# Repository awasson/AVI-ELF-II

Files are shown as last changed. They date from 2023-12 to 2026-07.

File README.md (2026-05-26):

# AVI ELF II Rev D Variant

**The AVI ELF II Rev D Variant is a reproduction of the RCA  CDP1802-based computer kit by Netronics Research and Development Limited.**

ELF II Rev D Variant

The AVI ELF II Rev D Variant single board microcomputer is a replica of the Netronics ELF II microcomputer that was reimagined by the late Ed Keefe (1964-2022) to maintain the aesthetic of the original ELF II, with additional onboard RAM and daughter cards for flexibility of keypad encoders and display drivers.

This project is ongoing with the support of [Josh Bensadon](https://github.com/JoshBensadon), [Andrew Wasson](https://github.com/awasson), Walter Miraglia, [Costas Skordis](https://github.com/cskordis) and Rizal Acob. Below you will find a stable version of the PCB gerber files, bill of materials. 

[The Assembly Manual](https://github.com/awasson/AVI-ELF-II/wiki/AVI-ELF-II-Detailed-Assembly-Notes) is in the Wiki and this covers building the mainboard and the expansion boards. 

**There are a number of differences between the AVI ELF II and the original:**

* Power on/off toggle switch with power status LED.
* Power is from a single 6 to 9 volt DC supply that supplies the board and expansion cards. Suitable for use with typical 9 volt adapter with barrel connector (center positive). If a V7805-2000R (DC DC CONVERTER 5V 10W) is used in place of the LM7805 voltage regulator, up to 2A of current is available for the board and expansion boards.
* Optional on-board DC-DC coverter for +8 volt / -8 volt supply for original Netronics Giant Board.
* 32KB on-board RAM with ability to adjust RAM size from 256 Bytes to 32KB.
* Optional onboard RAM battery backup.
* Keypad uses modern Cherry MX compatible keyswitches.
* The keypad input switch has improved debouncing over the original ELF II keypad.
* Optional raised Keypad to approximate height of keypad on the original Netronics ELF II.
* Onboard Data Display options for original HP 5082-7740 7-Segment Displays or HP 5082-7340 Dot Matrix LED Display.
* Optional raised display boards for TIL 311 or Dot Matrix Address and Data Displays. 

### What does it do?
Initially, we approached this project with the goal to faithfully reporduce the original Netronics ELF II with added flexibility to choose several LED display types, maximize user RAM for programs and use modern keyswitches. We also planned to add a modern equivalent of the Netronics Giant Board called the Hyperboard. As we workeed through development and testing, we realized that the ELF II provides the perfect springboard to support a variety of 1802 powered systems.

**A faithful reproduction of the original ELF II**\
If all you are looking for is a journey back to the late 70's, with a trusty ELF II and all of the RAM you could possibly use then, the AVI ELF II main board is all you need. It will respond and function as an exact replica of the original and if you squint at it from several feet away, it looks pretty close to the real McCoy. If you want to have the expansion possibilities that you would have enjoyed with the original system expanded with a Netronics Giant Board and the Giant Monitor, you can add a AVI Hyperboard to the mix.   

**A state of the art (circa 1979) ELF II workstation**\
The combination of an AVI ELF II main board, AVI Hyperboard (or Netronics Giant Board) and the AVI Reproduction Full BASIC Math/ROM Card, provides the top of the line Netronics ELF II microcomputer workstation of the time. It can be paired with the original ASCII keyboard/display or a serial terminal. Power on and it boots into the Giant Monitor where you can run, inspect or program in machine language or type in 00 (RUN) 0003 on the HEX keypad and it boots into Netronics Basic Level III (By Larry Sandlin) and you can use all of the built in RPN Math Co-processor features (bugs and all). Details to come in a new wiki page under development.    

**An ELF2K compatible ELF/OS machine with the Aesthetics and features of the ELF II platform**\
Uses the STG ELF2K to ELF II board and AVI ELF II TIL311 6-Digit Display Card described below.\
More details to come... 

**An RCA VIP Capable ELF II**\
Uses the ELF II SD Card and VIP Keyboard For ELF II described below. Optionally add Cassette Board for loading and saving to cassette tape.\
More details to come... 

**An RCA Studio II Capable ELF II**\
In development. Will require the VIP Keyboard for ELF II and secondary VIP Keyboard for ELF II + the Hyperboard or ELF II SD Card board.\
More details to come... 

### Build Notes & Assembly Manual
* [Detailed Assembly Notes](https://github.com/awasson/AVI-ELF-II/wiki/AVI-ELF-II-Detailed-Assembly-Notes)

### Design Files:
* [Schematic](notes/ELF-II/AVIELF2v1-Sch.pdf)
* [Bill of Materials](notes/ELF-II/AVI%20ELF%20II%20Final%20BOM.xlsx)
* [FAB Files](gerbers/ELF-II/AVIELF2v1-Gerbers.zip)

## Expansion Boards
Aside from the novelty of having a retro-replica of one of the most sought after Cosmac ELF variants, the fun begins when you add expansion boards to add features and extend the capabilities of the ELF II microcomputer. Several Expansion boards have been designed to enhance and extend the ELF II. These were designed primarily for use with the AVI ELF II but it is quite possible that many will work with an orginal Netronics ELF II. 

* **AVI Hyperboard 2.0 Expansion Card**\
The Hyperboard is a modern take on the Netronics ELF II Giant Board which includes additional RAM and EEPROM, input/output ports and serial connections with 32KB RAM / 32KB EPROM, CD1852 Byte-Wide Input/Output Ports, CD1854 UART, Cassette IN/OUT with proto area. The board was slightly revised in 2026 to add the ability to reserve/allocate address space on the address bus for use with add-on boards that have their own boot loading software on board, like the Netronics BASIC/MATH/ROM board.\
\
The original Hyperboard is documented for historical usage, in the [Hyperboard 1.0 Build Notes and Assembly Manual](https://github.com/awasson/AVI-ELF-II/wiki/AVI-Hyperboard-Expansion-Card-Assembly-Notes).\
\
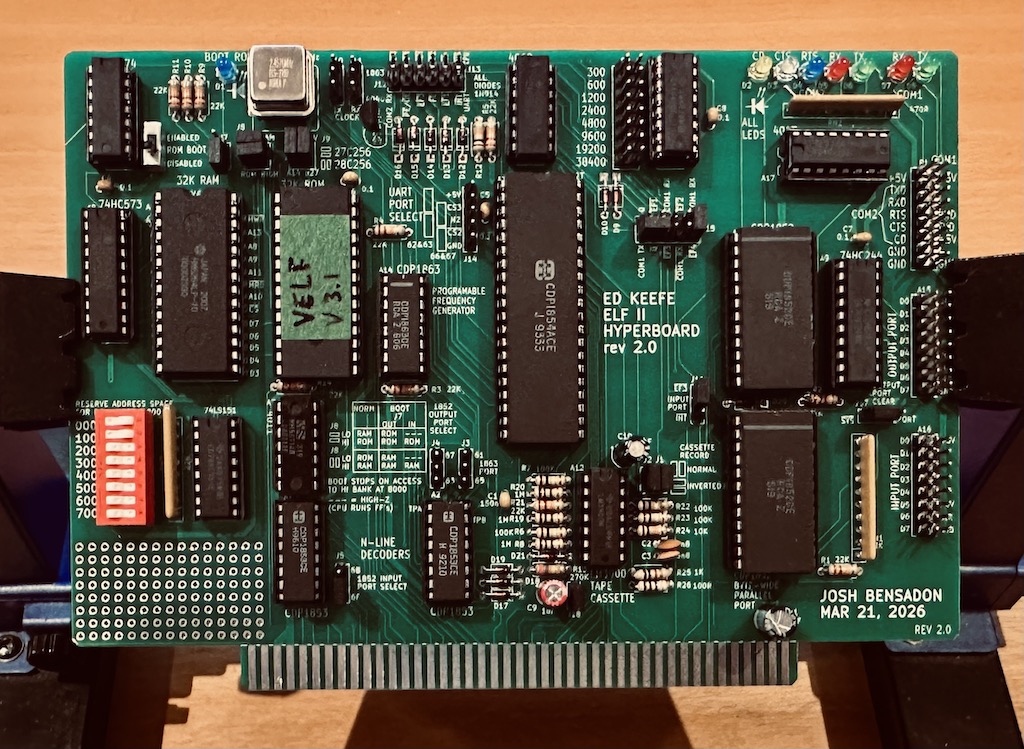
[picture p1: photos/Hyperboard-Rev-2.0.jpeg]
\
\
If the goal for your AVI ELF II is a fully expanded period computer from the late 1970's, the Hyperboard is a good addition to begin with. The Hyperboard will run new firmware readily and also runs period software including the Netronics Giant Monitor for automating entry, inspection and running programs. The Hyperboard also enables loading and saving programs from cassete tape.
   * [Get the schematics here](notes/Hyperboard-Rev-2/AVIELF2HYPERBOARD-KiCad-Rev2.pdf)
   * [Get the Gerber Files here](gerbers/Hyperboard-Rev-2/AVIELF2HYPERBOARD-Rev-2-gerbers.zip)
   * [Build Notes and Assembly Manual](https://github.com/awasson/AVI-ELF-II/wiki/AVI-Hyperboard-Rev-2.0-Expansion-Card-Assembly-Notes)<br/><br/>

* **STG ELF 2K Disk for ELF II Card**\
Uses Spare Time Gizmos ELF 2K Firmware to add a Compact Flash Card "Hard Disk" to use with the ELF/OS Disk Operating System. Provides 32KB RAM / 32KB EPROM, 16C450 UART, Serial Communications with FTDI connections, USB FT232RL device, IDE connection, CF Card socket and Real Time Clock chip.\
\
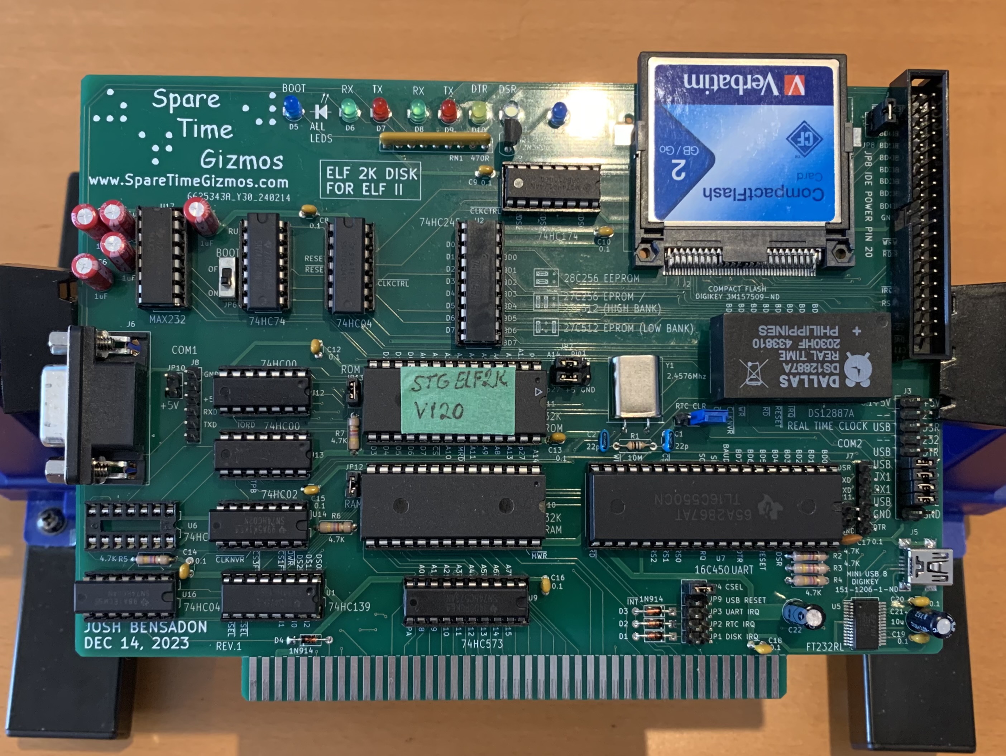
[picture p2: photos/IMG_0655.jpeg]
IMG STG CARD
\
\
If the goal for your AVI ELF II is to have a retro-modern 1802 system capable of running the ELF/OS disk operating system, using a compact flash card as a hard drive with a RS232 Serial connection up to BAUD 19200 and a real time clock, the ELF 2K for ELF II card covers all of the bases to get you there and the STG firmware provides additional system tools and programming languages. 
   * [Get the schematics here](notes/AVIELFSTGDISK0/AVIELFSTGDISK0-SCH.pdf)
   * [Get the Gerber Files here](gerbers/AVIELFSTGDISK0/AVIELFSTGDISK0-Gerbers.zip)
   * [Build Notes and Assembly Manual](https://github.com/awasson/AVI-ELF-II/wiki/STG-ELF-2K-Disk-for-ELF-II-Card-Assembly-Notes)<br/><br/>

* **ELF II SD Card**\
With 128K RAM, 32K EEPROM, TTL and Serial terminal connections and an SD Card for storage, the ELF II SD Card board provides the electronics and software to turn your AVI ELF II into a powerful RCA VIP compatible machine that is capable of reading, loading and running your software library of VIP and Chip8 programs just like the original RCA VIP.\
\
**Note:** For full VIP compatibility, the VIP Keyboard For ELF II described below is required.\
\
ELF II SD Card Image
   * [Get the schematics here](notes/AVIELF2SD/AVIELF2SD-SCH.pdf)
   * [Get the Gerber Files here](gerbers/AVIELF2SD/AVIELF2SD-Gerbers.zip)
   * [Build Notes and Assembly Manual](https://github.com/awasson/AVI-ELF-II/wiki/ELF-II-SD-Card-Detailed-Assembly-Notes)<br/><br/>

* **AVI ASCII Keyboard Rev D**\
The AVI ASCII Keyboard Rev D is a replica and amalgamation of the two ASCII keyboards that Netronics produced for their ELF II and Explorer 85 single board computers. The AVI ASCII Keyboard Rev D can operate as a stand alone keyboard with its onboard ac/dc power supply and parallel port or it can be supplied the +5, -12v & GND from an ELF II equipped with a Giant Board or Hyperboard. With an AVI ASCII Keyboard Rev D + a Giant Board & RAM Boards OR the AVI Hyperboard, your ELF II will be able to use a full ASCII keyboard to load ELF II software like Netronics Tiny Basic (from cassette) and use the ELF II onboard Pixie display chip just as you would in 1979 OR you can add the Reproduction Full BASIC Math/ROM Card and run Netronics BASIC Level III.\
\
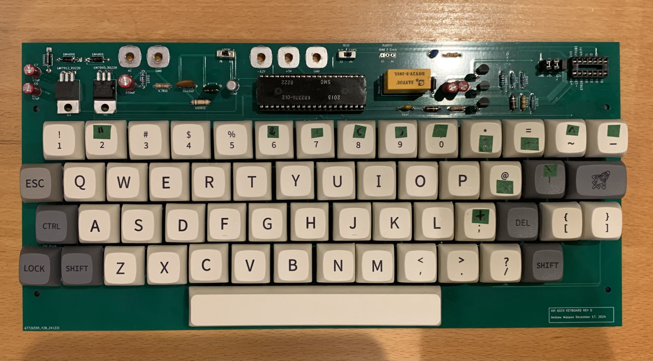
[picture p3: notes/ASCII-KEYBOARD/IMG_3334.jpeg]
ASCII KEYBOARD PCB

    * [Get the schematics here](https://github.com/awasson/AVI-ELF-II/blob/main/notes/ASCII-KEYBOARD/Netronics%20ASCII%20Keyboard.pdf)
    * [Get the BOM here](https://github.com/awasson/AVI-ELF-II/blob/main/notes/ASCII-KEYBOARD/Netronics-ASCII-Keyboard-BOM.xlsx)
    * [Get the Gerber Files here](gerbers/ASCII-KEYBOARD/Gerbers.zip)
    * [Build Notes and Assembly Manual](https://github.com/awasson/AVI-ELF-II/wiki/AVI-ELF-II-Keyboard-Rev-D)<br/><br/>

* **AVI Reproduction Full BASIC Math/ROM Card**\
The AVI Full BASIC Math/ROM Card is reproduction of the board that was made available for the Netronics ELF II. This board was just created and we are buuilding and testing so more info will be added as we run it through its paces.\
\
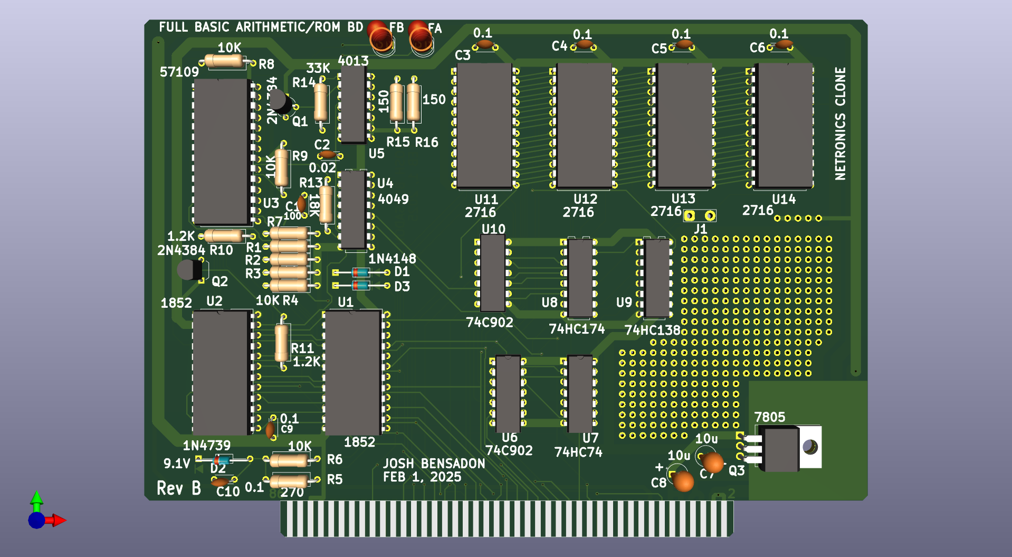
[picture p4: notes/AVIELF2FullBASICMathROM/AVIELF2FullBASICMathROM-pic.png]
AVI Reproduction Full BASIC Math/ROM Card

    * [Get the schematics here](https://github.com/awasson/AVI-ELF-II/blob/main/notes/AVIELF2FullBASICMathROM/AVIELF2FullBASICMathROM.pdf)
    * [Get the Gerber Files here](https://github.com/awasson/AVI-ELF-II/blob/main/gerbers/AVIELF2FullBASICMathROM/AVIELF2FullBASICMathROM-GERBERS.zip)<br/><br/>

* **VIP Keyboard For ELF II**\
The VIP Keyboard for ELF II is the companion card for the ELF II SD Card described above, providing the correct keyboard orientation and mapping for the RCA VIP system with a Q LED and a micro speaker to play the beeps tones and notifications that the original VIP plays.\
\
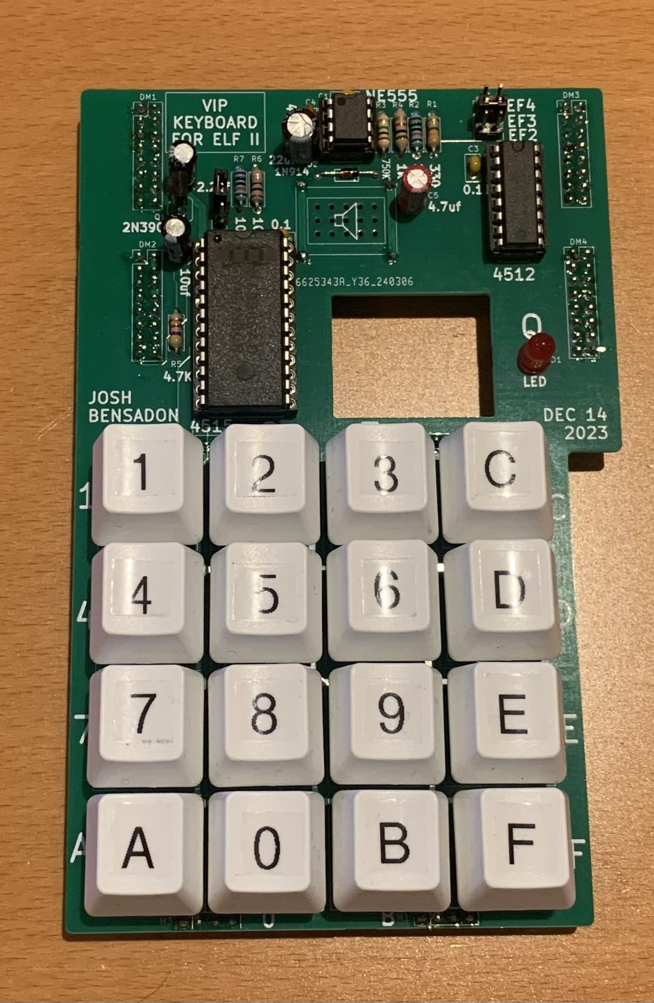
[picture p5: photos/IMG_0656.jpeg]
\
   * [Get the schematics here](notes/AVIELF2-VIP/AVIELF2-VIP-SCH.pdf)
   * [Get the Gerber Files here](gerbers/AVIELF2-VIP/AVIELF2-VIP-Gerbers.zip)
   * [Build Notes and Assembly Manual](https://github.com/awasson/AVI-ELF-II/wiki/VIP-Keyboard-for-The-AVI-ELF-II-Board-Assembly-Notes)<br/><br/>
 
* **VIP Secondary Keyboard for ELF II**\
For use with VIP Keyboard for ELF II as shown above for multiplayer game support.\
\
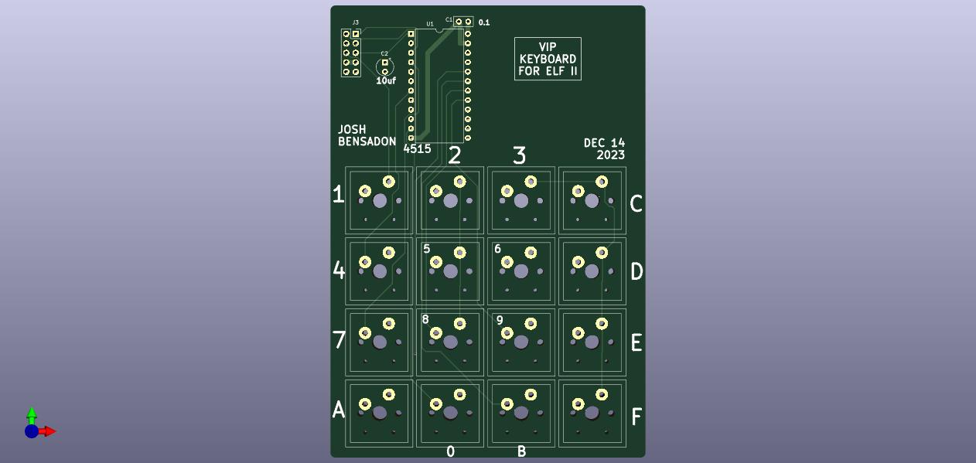
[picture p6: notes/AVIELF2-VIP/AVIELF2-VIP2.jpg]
IMG VIP AUX KEYPAD

   * [Get the schematics here](notes/AVIELF2-VIP/AVIELF2-VIP2-SCH.pdf)
   * [Get the Gerber Files here](gerbers/AVIELF2-VIP/AVIELF2-VIP2-Gerbers.zip)
   * [Build Notes and Assembly Manual](https://github.com/awasson/AVI-ELF-II/wiki/VIP-Secondary-Keyboard-for-The-AVI-ELF-II-Board-Assembly-Notes)<br/><br/>

* **AVI ELF II Cassette Interface Card**\
An expansion card to add the ability to load and save programs to cassette tape using the Cassette In | Out jacks on the ELF II main board or Cassette In | Out on the cassette board itself. This makes a useful companion board for the ELF II SD Card for loading and saving VIP programs and data to cassette.\
\
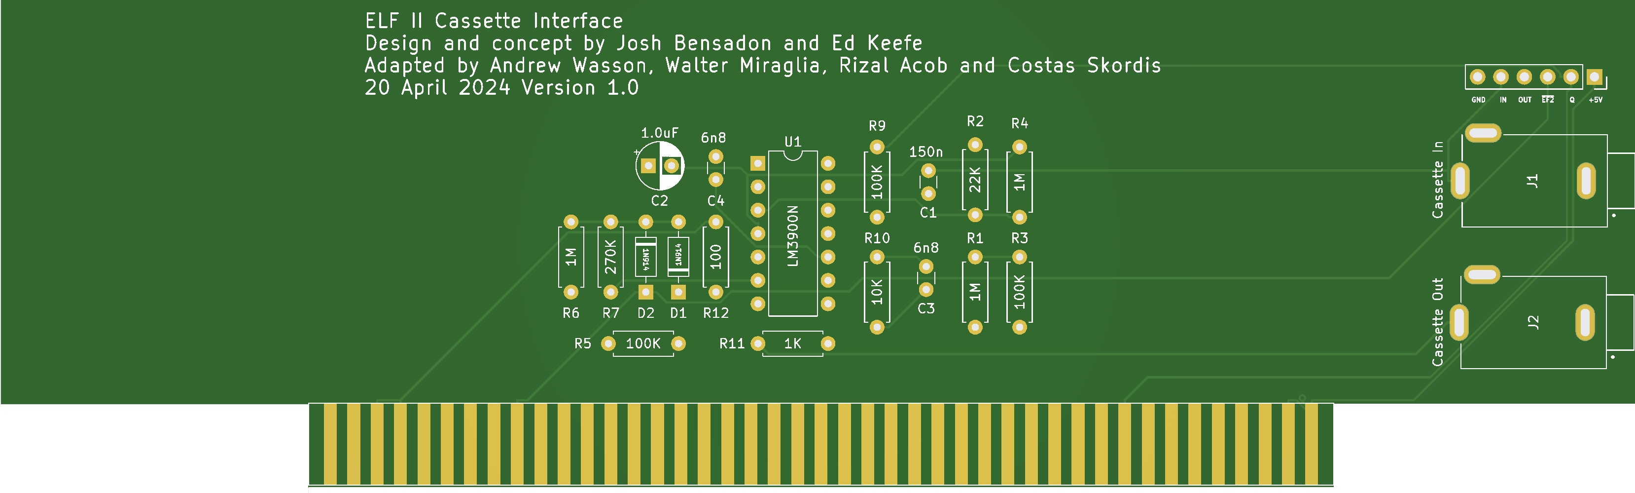
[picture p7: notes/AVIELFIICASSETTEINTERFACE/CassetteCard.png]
IMG VAVI ELF II Cassette Interface Card

   * [Get the schematics here](notes/AVIELFIICASSETTEINTERFACE/ELFIICassetteCircuitSchematic.pdf) 
   * [Get the Gerber Files here](gerbers/AVIELFIICASSETTEINTERFACE/gerbers.zip)
   * Build Notes and Assembly Manual in progress.<br/><br/>

* <strong><span id="id-protoboard">Protoboard</strong>\
Full sized expansion card with 86 position edge connection for prototyping cicuitry.\
\

   * [Get the Gerber Files here](gerbers/AVIELF2Prototyping/AVIELF2Prototyping-Gerbers.zip)<br/><br/>

* **ELF II LED Matrix Display**\
A plugin display board that is located directly in front of the Hex keypad, replacing the original LED data display to provide an updated, larger, dot matrix display with 4 digit address and 2 digit data, plus additional messaging to indicate load mode and reset.\
\
<br/>
   * [Get the schematics here](notes/AVIELF2DISPLAYMAX7219/AVIELF2DISPLAYMAX7219-SCH.pdf) 
   * [Get the Gerber Files here](gerbers/AVIELF2DISPLAYMAX7219/AVIELF2DISPLAYMAX7219-Gerbers.zip)
   * [Get the Hex file for programming the Two PIC 16F1826 Chips](notes/AVIELF2DISPLAYMAX7219/HexDisp.HEX)
   * [Build Notes and Assembly Manual](https://github.com/awasson/AVI-ELF-II/wiki/ELF-II-LED-Matrix-Display-Assembly-Notes)<br/><br/>

* **AVI ELF II TIL311 6-Digit Display Card**\
A plugin display board that is located directly in front of the Hex keypad, replacing the original LED data display to provide a 6-digit display using the TIl311 displays with 4 digit address and 2 digit data.\
\
**Note:** TIL311 displays draw a lot of current. We highly recommend using the V7805-2000R in place of the LM7805 voltage regulator on your ELF II Main Board if you add the 6-Digit Display Card to your system; the V7805-2000R runs extremely cool even when powering the ELF II Main Board + TIL311 6-Digit Display Card + an expansion card like the Hyperboard or STG ELF 2K Disk for ELF II Card. If you choose to use an LM7805 regulator, make sure to use a decent heatsink to dissipate the heat and do not leave your system unattended when powered on.\
\
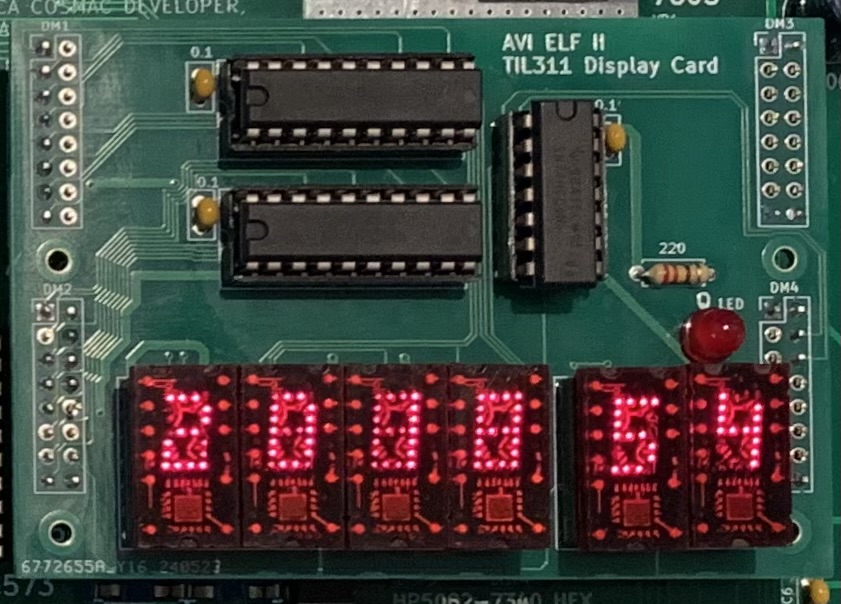
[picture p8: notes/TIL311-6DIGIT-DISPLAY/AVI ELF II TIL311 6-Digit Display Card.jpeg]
<br/>
   * [Get the schematics here](notes/TIL311-6DIGIT-DISPLAY/AVI%20ELF%20II%20TIL311%206-Digit%20Display%20Card.pdf) 
   * [Get the Gerber Files here](gerbers/TIL311-6DIGIT-DISPLAY/gerbers.zip)
   * [Build Notes and Assembly Manual ](https://github.com/awasson/AVI-ELF-II/wiki/AVI-ELF-II-TIL311-6%E2%80%90Digit-Display-Card-Assembly--Notes)

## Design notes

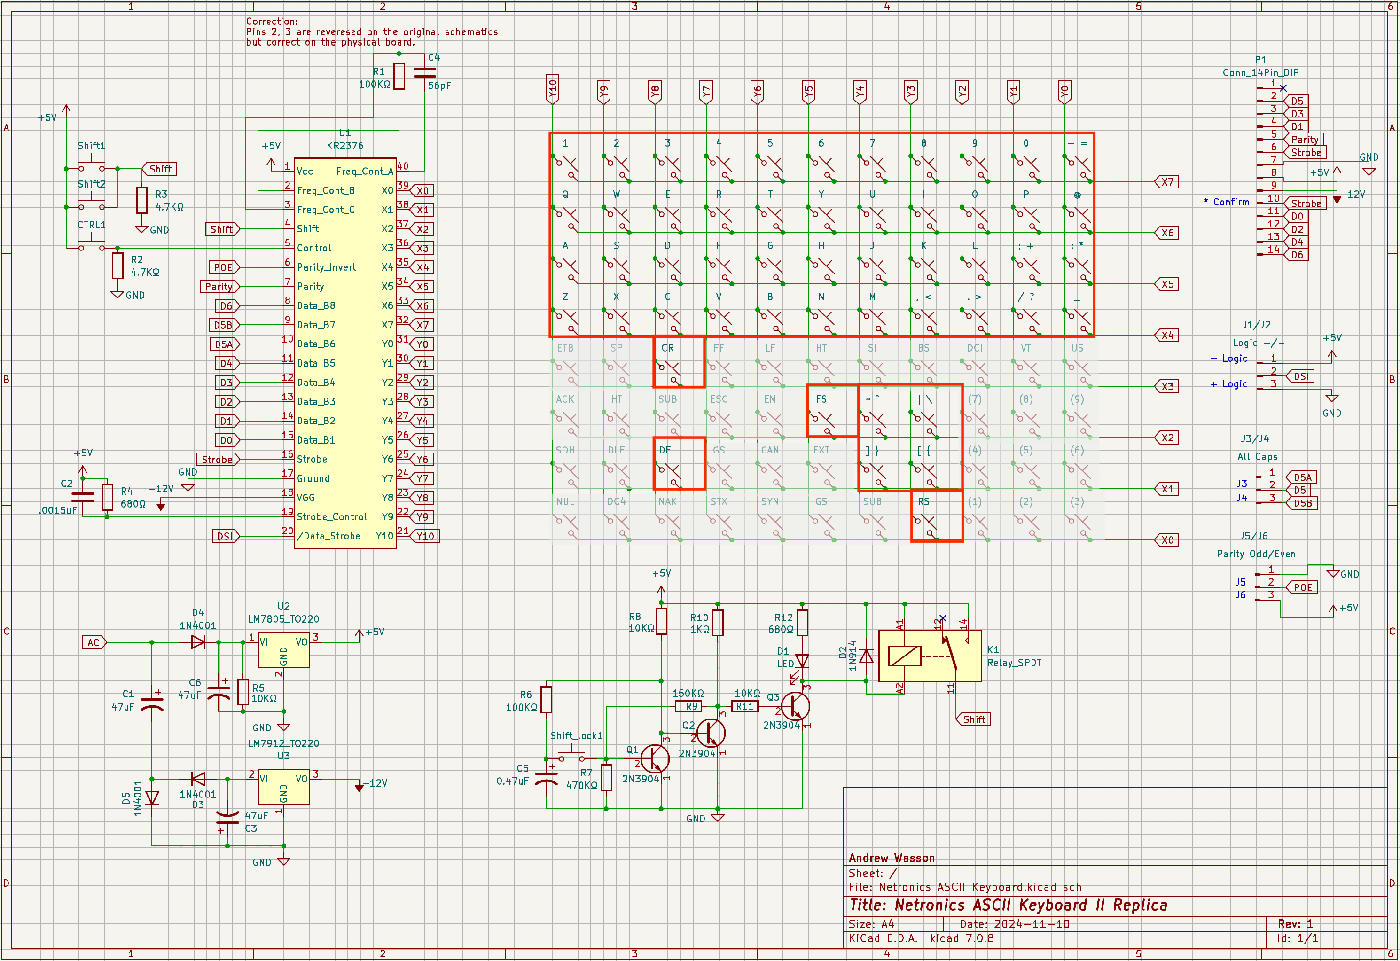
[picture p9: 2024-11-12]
notes/ASCII-KEYBOARD/Netronics ASCII Keyboard Schematic (REV1).png

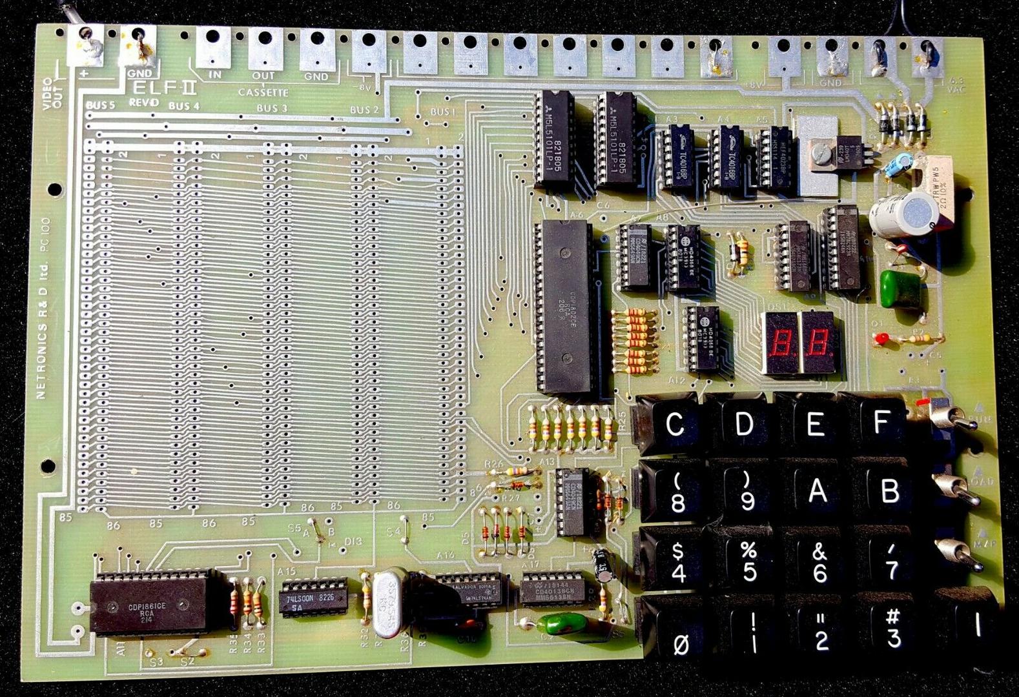
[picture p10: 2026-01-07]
photos/1_1019c1ddc17f050e53c220ed2bfb8927.jpg

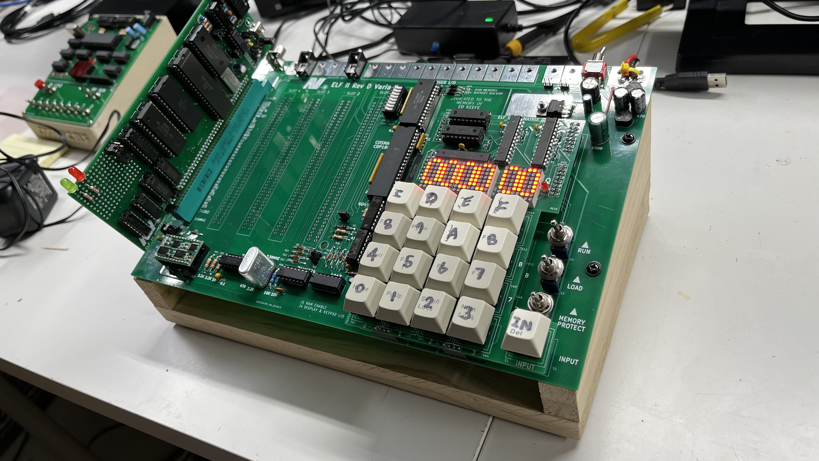
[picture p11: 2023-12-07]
photos/72189111114__0A851230-6ECE-4E1C-8138-CF7994627F6F.fullsizerender.jpg

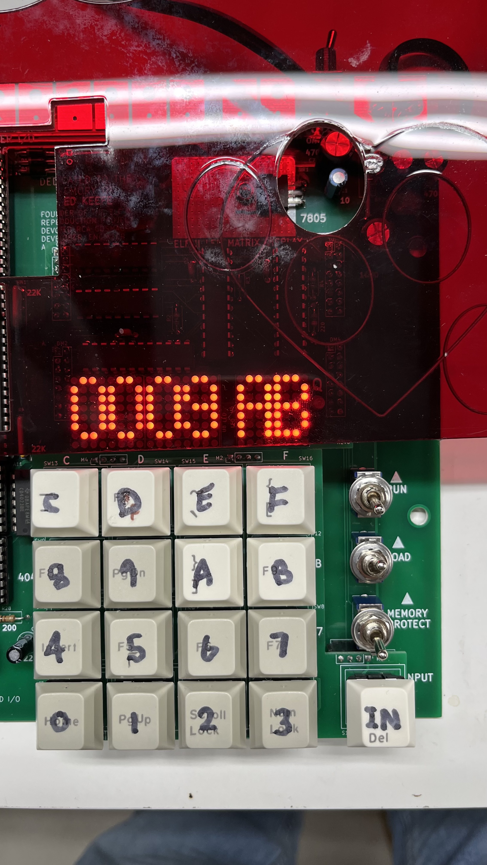
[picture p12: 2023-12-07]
photos/72188935161__602F3ED4-9279-4573-AC2E-27C6731AC719.fullsizerender.jpeg

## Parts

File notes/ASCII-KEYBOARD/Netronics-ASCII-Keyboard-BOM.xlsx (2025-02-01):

Qty | Reference(s) | Value | Description | Footprint | Datasheet | DIGIKEY.CA
1 | PCB |  | JLCPCB $66.52 CAD for 5 boards |  |  | https://jlcpcb.com/
 | IC's
1 | U1 | KR2376 | Keyboard Encoder Chip. | Package_DIP:DIP-40_W15.24mm_LongPads | http://www.ic-on-line.com/download.php?id=1101543&pdfid=78683690CF6B430CD3E2B1E2D98D2CBE&file=0052\kr2376_394265.pdf | https://theelectronicgoldmine.com/en-ca/products/g28358
1 | U2 | LM7805_TO220 | Regulator_Linear:LM7805_TO220 | Package_TO_SOT_THT:TO-220-3_Horizontal_TabDown | https://www.onsemi.cn/PowerSolutions/document/MC7800-D.PDF | https://www.digikey.ca/en/products/detail/texas-instruments/LM7805CT-NOPB/3901929
1 | U3 | LM7912_TO220 | Regulator_Linear:LM7912_TO220 | Package_TO_SOT_THT:TO-220-3_Horizontal_TabDown | https://www.onsemi.com/pub/Collateral/MC7900-D.PDF | https://www.digikey.ca/en/products/detail/texas-instruments/LM7912CT-NOPB/6355
 | SEMICONDUCTORS
3 | Q1, Q2, Q3 | 2N3904 | Transistor_BJT:2N3904 | Package_TO_SOT_THT:TO-92_Inline | https://www.onsemi.com/pub/Collateral/2N3903-D.PDF | https://www.digikey.ca/en/products/detail/onsemi/2N3904BU/1413
1 | D1 | LED | Device:LED | LED_THT:LED_D3.0mm | ~ | https://www.digikey.ca/en/products/detail/sunled/XLUR12D/4745846
4 | D2, D3, D4, D5 | 1N4001 | Diode:1N4001 | Diode_THT:D_DO-35_SOD27_P7.62mm_Horizontal | http://www.vishay.com/docs/85622/1n914.pdf | https://www.digikey.ca/en/products/detail/onsemi/1N4001RLG/917621
 | CAPACITORS
1 | C2 | .0015uF | Device:C | Capacitor_THT:C_Axial_L3.8mm_D2.6mm_P7.50mm_Horizontal | ~ | https://www.digikey.ca/en/products/detail/vishay-beyschlag-draloric-bc-components/K152K15X7RF53L2/2821121
1 | C3 | .047uF | Device:C | Capacitor_THT:C_Axial_L3.8mm_D2.6mm_P7.50mm_Horizontal | ~ | https://www.digikey.ca/en/products/detail/vishay-beyschlag-draloric-bc-components/K152K15X7RF53L2/2821121
1 | C4 | 10uF | Device:C_Polarized_US | Capacitor_THT:CP_Radial_D5.0mm_P2.00mm | ~ | https://www.digikey.ca/en/products/detail/panasonic-electronic-components/ECA-1EM100B/2688676
1 | C5 | 56pF | Device:C | Capacitor_THT:C_Axial_L3.8mm_D2.6mm_P7.50mm_Horizontal | ~ | https://www.digikey.ca/en/products/detail/vishay-beyschlag-draloric-bc-components/K560J15C0GF5TL2/286464
2 | C6, C7 | 47uF | Device:C_Polarized_US | Capacitor_THT:CP_Radial_D5.0mm_P2.00mm | ~ | https://www.digikey.ca/en/products/detail/panasonic-electronic-components/EEU-FR1J470/3072280
1 | C8 | 100uF | Device:C_Polarized_US | Capacitor_THT:CP_Radial_D5.0mm_P2.00mm | ~ | https://www.digikey.ca/en/products/detail/rubycon/35ZLH100MEFC6-3X11/3134256
1 | C9 | 0.47uF | Device:C_Polarized_US | Capacitor_THT:CP_Radial_D5.0mm_P2.00mm | ~ | https://www.digikey.ca/en/products/detail/w%C3%BCrth-elektronik/860160672001/5727809
 | RESISTORS
2 | R1, R7 | 100K | Device:R | Resistor_THT:R_Axial_DIN0207_L6.3mm_D2.5mm_P7.62mm_Horizontal | ~ | https://www.digikey.ca/en/products/detail/stackpole-electronics-inc/CF14JT100K/1741263
2 | R2, R3 | 4.7K | Device:R | Resistor_THT:R_Axial_DIN0207_L6.3mm_D2.5mm_P7.62mm_Horizontal | ~ | https://www.digikey.ca/en/products/detail/stackpole-electronics-inc/CF14JT4K70/1741428
1 | R4 | 680K | Device:R | Resistor_THT:R_Axial_DIN0207_L6.3mm_D2.5mm_P7.62mm_Horizontal | ~ | https://www.digikey.ca/en/products/detail/stackpole-electronics-inc/CF14JT680K/1741491
3 | R6, R9, R12 | 10K | Device:R | Resistor_THT:R_Axial_DIN0207_L6.3mm_D2.5mm_P7.62mm_Horizontal | ~ | https://www.digikey.ca/en/products/detail/stackpole-electronics-inc/CF14JT10K0/1741265
1 | R8 | 470K | Device:R | Resistor_THT:R_Axial_DIN0207_L6.3mm_D2.5mm_P7.62mm_Horizontal | ~ | https://www.digikey.ca/en/products/detail/stackpole-electronics-inc/CF14JT470K/1741442
1 | R10 | 150K | Device:R | Resistor_THT:R_Axial_DIN0207_L6.3mm_D2.5mm_P7.62mm_Horizontal | ~ | https://www.digikey.ca/en/products/detail/yageo/MFR-25FRF52-150K/14631
1 | R11 | 1K | Device:R | Resistor_THT:R_Axial_DIN0207_L6.3mm_D2.5mm_P7.62mm_Horizontal | ~ | https://www.digikey.ca/en/products/detail/stackpole-electronics-inc/CF14JT1K00/1741314
1 | R13 | 680Ω | Device:R | Resistor_THT:R_Axial_DIN0207_L6.3mm_D2.5mm_P7.62mm_Horizontal | ~ | https://www.digikey.ca/en/products/detail/stackpole-electronics-inc/CF14JT680R/1741489
 | KEYSWITCHES
55 | Momentary Pushbutton | 1 | Keyswitch. Amazon or similar. | Switch_Keyboard_Cherry_MX:SW_Cherry_MX_PCB_1.00u | ~ | https://www.amazon.ca/dp/B0BXZXZX74
55 | Keycaps
 | MISC H/W
1 | K1 | Relay_SPDT | Relay:G5V-2 | Relay_THT:Relay_DPDT_Omron_G5V-2 | http://omronfs.omron.com/en_US/ecb/products/pdf/en-g5v_2.pdf | https://www.digikey.ca/en/products/detail/omron-electronics-inc-emc-div/G5V-2-DC5/87819
1 | J1/J2 | Logic +/- | 3-pin header Through Hole 0.100" (2.54mm) | Connector_PinHeader_2.54mm:PinHeader_1x03_P2.54mm_Vertical | ~ | https://www.digikey.ca/en/products/detail/sullins-connector-solutions/PREC040SAAN-RC/2774814
1 | J3/J4 | All Caps | 3-pin header Through Hole 0.100" (2.54mm) | Connector_PinHeader_2.54mm:PinHeader_1x03_P2.54mm_Vertical | ~ | https://www.digikey.ca/en/products/detail/sullins-connector-solutions/PREC040SAAN-RC/2774814
1 | J5/J6 | Parity Odd/Even | 3-pin header Through Hole 0.100" (2.54mm) | Connector_PinHeader_2.54mm:PinHeader_1x03_P2.54mm_Vertical | ~ | https://www.digikey.ca/en/products/detail/sullins-connector-solutions/PREC040SAAN-RC/2774814
2 | Stiffeners | 540-0G990743 | Keyboard Stiffeners for space bar |  |  | https://www.mouser.ca/ProductDetail/540-0G990743

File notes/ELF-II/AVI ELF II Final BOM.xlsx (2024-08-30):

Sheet: DigiKey.ca
QUANTITY | PART # | PART | DESCRIPTION | NOTES | DigiKey
IC's
1 | A1 | CY62256 | SRAM 256K-Bit (32Kx8) | Jameco Electronics: https://www.jameco.com/z/HM62256LP-70-HITACHI-IC-62256LP-CMOS-SRAM-256K-Bit-32Kx8-70ns-Low-Power_82472.html | ~
1 | A2 | 74HC573 | D-Type Transparent Latch |  | https://www.digikey.ca/en/products/detail/texas-instruments/SN74HC573AN/277242
2 | A3, A4 | 4016 | Bilateral, FET Switches |  | https://www.digikey.ca/en/products/detail/texas-instruments/CD4016BE/67251
1 | A5 | 4023 | NAND Gate IC 3 Channel |  | https://www.digikey.ca/en/products/detail/texas-instruments/CD4023BE/67265
1 | A6 | CDP1802ACE | RCA CMOS 8-Bit Microprocessor | * Ebay or other surplus source | ~
2 | A7, A11 | 4050 | Buffer, Non-Inverting |  | https://www.digikey.ca/en/products/detail/texas-instruments/CD4050BE/67303
1 | A8, A12 *Used with onboard 7-segment LED Display option | DM9368 | 7-Segment Decoder/Driver/Latch | * Ebay or other surplus source | ~
1 | A9 | 74C173 | Flip Flop D-Type |  | https://www.digikey.ca/en/products/detail/texas-instruments/CD74HC173E/1506733
1 | A10 | MM74C922 | 16-20 Key Encoder DIP 18-pin | Jameco Electronics: https://www.jameco.com/z/74C922-Major-Brands-IC-74C922-16-20-Key-Encoder-DIP-18-pin_44564.html | ~
2 | A13, A18 | 4049 | Inverter IC 6 Channel |  | https://www.digikey.ca/en/products/detail/texas-instruments/CD4049UBE/67301
1 | A14 | CDP1861 | RCA Pixie Graphics Video Display Controller | * Ebay or other surplus source | ~
1 | A15 | 74LS00 | NAND Gate | * Note: This is an LS device and the clock may not operate correctly if an HC or other type of TTL device is used. | https://www.digikey.ca/en/products/detail/texas-instruments/SN74LS00N/277272
1 | A16 | 74HC74 | D-Type Flip Flop | * Note: This is an HC device and the clock may not operate correctly if an LS or other type of TTL device is used. | https://www.digikey.ca/en/products/detail/texas-instruments/CD74HCT74E/38762
1 | A17 | 4013 | D-Type Flip Flop |  | https://www.digikey.ca/en/products/detail/texas-instruments/CD4013BE/67245
Semiconductors
12 | D1, D2, D5, D6, D7, D8, D9, D10, D11, D12, D13, D14 | 1N914 | Diode 100 V 200mA Through Hole DO-35 |  | https://www.digikey.ca/en/products/detail/onsemi/1N914/978749
1 | D3 | 1N4001 | Diode 50 V 1A Through Hole Axial |  | https://www.digikey.ca/en/products/detail/onsemi/1N4001G/1485468
3 | D15, D16, D17 | 1N5819 | Schottky Diode 40V 1A |  | https://www.digikey.ca/en/products/detail/stmicroelectronics/1N5819/1037326
1 | VR1 Option #1 Voltage regulator | LM7805_TO220 | LM7805 5V 1.5A Voltage Regulator | Standard 1.5A 5V regulator | https://www.digikey.ca/en/products/detail/texas-instruments/LM7805CT-NOPB/3901929
1 | VR1 Option #2 Voltage regulator | V7805-2000R | DC DC CONVERTER 5V 10W | 5v 2A. Runs cooler with more current capacity | https://www.digikey.ca/en/products/detail/cui-inc/V7805-2000R/2352147
1 | Y1 | 3.58 | 3.579545MHZ Colorburst Crystal |  | https://www.digikey.ca/en/products/detail/raltron-electronics/a-3-579545-18/10271744
1 | U1 *Optional for +8v / 0 / -8v supply on expansion bus | IB0512S-W75R3 | DC DC Converter 12V 744MW |  | https://www.digikey.ca/en/products/detail/mornsun-america-llc/IB0512S-W75R3/16571407
Displays
2 | LED1, LED2 | LED | 5mm LED Red Diffused |  | https://www.digikey.ca/en/products/detail/sunled/XLUR12D/4745846
1 | DISP1, DISP2 * 7-segment LED | 5082-7740 | Hewlett-Packard 5082-7740 Red common cathode seven segment digital display | * Ebay or other surplus source
2 | DISP3, DISP4 * 4x7 Dot Matrix LED Display with logic driver | 5082-7340 | HP 5082-7340 Hexidecimal 4x7 Dot Matrix LED Display with logic driver | * Ebay or other surplus source
Capacitors
5 | C1, C16, C17, C18, C19 | 10uf Electrolytic | 10uf Electrolitic Radial Capacitor |  | https://www.digikey.ca/en/products/detail/panasonic-electronic-components/ECA-1EM100B/2688676
1 | C2 | 1000uf Electrolytic | 1000uf Electrolytic Radial Capacitor |  | https://www.digikey.ca/en/products/detail/rubycon/25PX1000MEFCT810X16/3134863
9 | C3, C4, C5, C6, C11, C14, C15, C20, C21 | 0.1uF | 100nf (0.1uf) Ceramic Capacitor |  | https://www.digikey.ca/en/products/detail/kemet/C320C104K5R5TA7317/6562447
1 | C7 | 18pf | 18pf Ceramic Capacitor |  | https://www.digikey.ca/en/products/detail/vishay-beyschlag-draloric-bc-components/K180J15C0GF5TL2/286458
1 | C8 | 10uf Electrolytic | 10uf Electrolitic Radial Capacitor |  | https://www.digikey.ca/en/products/detail/panasonic-electronic-components/ECA-1EM100B/2688676
1 | C9 | 10nf | 10nf Ceramic Capacitor |  | https://www.digikey.ca/en/products/detail/kemet/C320C103K3G5TA/6656406
1 | C10 | 330pf | 330pf Ceramic Capacitor |  | https://www.digikey.ca/en/products/detail/vishay-beyschlag-draloric-bc-components/K331K15X7RF5TL2/286523
1 | C12 | 1uf Electrolytic | 1uf Electrolytic Radial Capacitor |  | https://www.digikey.ca/en/products/detail/w%C3%BCrth-elektronik/860020672005/5727088
1 | C13 | 150nf | 150nf (0.15uf) Ceramic Capacitor |  | https://www.digikey.ca/en/products/detail/kemet/C320C154K5R5TA/818052
Resistors
2 | R1, R2 | 330 | 330 ohm Carbon Film Resistor |  | https://www.digikey.ca/en/products/detail/stackpole-electronics-inc/CF14JT330R/1741399
1 | R15 | 1K | 1 kilohm Carbon Film Resistor |  | https://www.digikey.ca/en/products/detail/stackpole-electronics-inc/CF14JT1K00/1741314
2 | R26, R29 | 47K | 47 kilohm Carbon Film Resistor |  | https://www.digikey.ca/en/products/detail/stackpole-electronics-inc/CF14JT47K0/1741444
1 | R28 | 200 | 200 ohm Carbon Film Resistor |  | https://www.digikey.ca/en/products/detail/stackpole-electronics-inc/CF14JT200R/1741336
2 | R30, R36 | 10K | 10 kilohm Carbon Film Resistor |  | https://www.digikey.ca/en/products/detail/stackpole-electronics-inc/CF14JT10K0/1741265
3 | R34, R35 | 2.2K | 2.2 kilohm Carbon Film Resistor |  | https://www.digikey.ca/en/products/detail/stackpole-electronics-inc/CF14JT2K20/1741321
1 | R31, R32 | 470R | 470 ohm Carbon Film Resistor | R31 was origninally spec'd for 2.2k but shoud be 470 ohm | https://www.digikey.ca/en/products/detail/stackpole-electronics-inc/CF14JT470R/1741440
1 | R33 | 1K | 1 kilohm Carbon Film Resistor |  | https://www.digikey.ca/en/products/detail/stackpole-electronics-inc/CF14JT1K00/1741314
2 | RN1, RN3 | 22K | RES ARRAY 4 RES 22K OHM 5SIP |  | https://www.digikey.ca/en/products/detail/bourns-inc/4605X-101-223LF/3593674
2 | RN2, RN4 | 22K | RES ARRAY 8 RES 22K OHM 9SIP |  | https://www.digikey.ca/en/products/detail/bourns-inc/4609X-101-223LF/3593668
2 | RN5, RN6 *Used with onboard 7-segment LED Display option | 120 | RES ARRAY 8 RES 120 OHM 16DIP |  | https://www.digikey.ca/en/products/detail/bourns-inc/4116R-1-121LF/1088613
Switches
1 | S2 | S2 | MEMORY PROTECT |  | https://www.digikey.ca/en/products/detail/e-switch/100SP1T1B4M2QE/378824
1 | S3 | S3 | LOAD |  | https://www.digikey.ca/en/products/detail/e-switch/100SP1T1B4M2QE/378824
1 | S4 | S4 | RUN |  | https://www.digikey.ca/en/products/detail/e-switch/100SP1T1B4M2QE/378824
1 | S5 | S5 | POWER |  | https://www.digikey.ca/en/products/detail/cit-relay-and-switch/ANT11TFHQE/12503364
17 | Hex Keypad + Input | SW1 - SW16 + S1 | Cherry type keyboard switch (Amazon 30 piece set) | Amazon: https://www.amazon.ca/dp/B0BXZXZX74
1 | DIP_SW1 | DIP_SW1 | 8 Position DIP Switch |  | https://www.digikey.ca/en/products/detail/grayhill-inc/76SB08T/726235
Connectors
1 | J1 | Barrel Power connector | Manufacturer Product Number PJ-002BH |  | https://www.digikey.ca/en/products/detail/cui-devices/PJ-002BH/408447
1 | CN1 | VIDEO OUT | Video Output Jack |  | https://www.digikey.ca/en/products/detail/cui-devices/RCJ-014/408490
1 | T1 | CASSETTE OUT | Audio Jack T1 |  | https://www.digikey.ca/en/products/detail/cui-devices/MJ-3536N/281264
1 | T2 | CASSETTE IN | Audio Jack T2 |  | https://www.digikey.ca/en/products/detail/cui-devices/MJ-3536N/281264
5 | P1, P2, P3, P4, P5 *Black TE Connectivity AMP Connectors | Optional Expansion Sockets | 86 Position Female Connector Non Specified - Dual |  | https://www.digikey.ca/en/products/detail/te-connectivity-amp-connectors/1-5530843-0/2310825
5 | P1, P2, P3, P4, P5 *Green EDAC Inc. | Optional Expansion Sockets | 86 Position Female Connector Non Specified - Dual |  | https://www.digikey.ca/en/products/detail/edac-inc/345-086-520-202/1294448
4 | DM1, DM2, DM3, DM4 *Optional for Raised Daughter Card Display | J1, J2, J3, J4 | 16 pin F Dual Row Socket |  | https://www.digikey.ca/en/products/detail/sullins-connector-solutions/PPPC082LFBN-RC/810248
5 | M1, M2, M3, M4, M5 * Optional For Raised Keypad | S7002-ND | 4 Position Header Connector 0.100" (2.54mm) |  | https://www.digikey.ca/en/products/detail/sullins-connector-solutions/PPTC041LFBN-RC/810144
Jumpers
8 | J2, J3, J4, J7, J9, J11, J+8V1, J-8V1 |  | Connector Header Through Hole 0.100" (2.54mm) |  | https://www.digikey.ca/en/products/detail/sullins-connector-solutions/PREC040SAAN-RC/2774814
Misc
2 | Triangular Wooden Side Rails |  | Veneered Wood: 2.75 inches tall, 7 inches long on the back and bottom ends with about a 1/8 inch bevel on the very front tip so it's not sharp down to a point.
1 | BATT1 | BATT | 5volt Battery Source for optional onboard battery backup for RAM

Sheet: DigiKey.com
QUANTITY | PART # | PART | DESCRIPTION | NOTES | DigiKey
IC's
1 | A1 | CY62256 | SRAM 256K-Bit (32Kx8) | Jameco Electronics: https://www.jameco.com/z/HM62256LP-70-HITACHI-IC-62256LP-CMOS-SRAM-256K-Bit-32Kx8-70ns-Low-Power_82472.html | ~
1 | A2 | 74HC573 | D-Type Transparent Latch |  | https://www.digikey.com/en/products/detail/texas-instruments/SN74HC573AN/277242
2 | A3, A4 | 4016 | Bilateral, FET Switches |  | https://www.digikey.com/en/products/detail/texas-instruments/CD4016BE/67251
1 | A5 | 4023 | NAND Gate IC 3 Channel |  | https://www.digikey.com/en/products/detail/texas-instruments/CD4023BE/67265
1 | A6 | CDP1802ACE | RCA CMOS 8-Bit Microprocessor | * Ebay or other surplus source | ~
2 | A7, A11 | 4050 | Buffer, Non-Inverting |  | https://www.digikey.com/en/products/detail/texas-instruments/CD4050BE/67303
1 | A8, A12 *Used with onboard 7-segment LED Display option | DM9368 | 7-Segment Decoder/Driver/Latch | * Ebay or other surplus source | ~
1 | A9 | 74C173 | Flip Flop D-Type |  | https://www.digikey.com/en/products/detail/texas-instruments/CD74HC173E/1506733
1 | A10 | MM74C922 | 16-20 Key Encoder DIP 18-pin | Jameco Electronics: https://www.jameco.com/z/74C922-Major-Brands-IC-74C922-16-20-Key-Encoder-DIP-18-pin_44564.html | ~
2 | A13, A18 | 4049 | Inverter IC 6 Channel |  | https://www.digikey.com/en/products/detail/texas-instruments/CD4049UBE/67301
1 | A14 | CDP1861 | RCA Pixie Graphics Video Display Controller | * Ebay or other surplus source | ~
1 | A15 | 74LS00 | NAND Gate | * Note: This is an LS device and the clock may not operate correctly if an HC or other type of TTL device is used. | https://www.digikey.com/en/products/detail/texas-instruments/SN74LS00N/277272
1 | A16 | 74HC74 | D-Type Flip Flop | * Note: This is an HC device and the clock may not operate correctly if an LS or other type of TTL device is used. | https://www.digikey.com/en/products/detail/texas-instruments/CD74HCT74E/38762
1 | A17 | 4013 | D-Type Flip Flop |  | https://www.digikey.com/en/products/detail/texas-instruments/CD4013BE/67245
Semiconductors
12 | D1, D2, D5, D6, D7, D8, D9, D10, D11, D12, D13, D14 | 1N914 | Diode 100 V 200mA Through Hole DO-35 |  | https://www.digikey.com/en/products/detail/onsemi/1N914/978749
1 | D3 | 1N4001 | Diode 50 V 1A Through Hole Axial |  | https://www.digikey.com/en/products/detail/onsemi/1N4001G/1485468
3 | D15, D16, D17 | 1N5819 | Schottky Diode 40V 1A |  | https://www.digikey.com/en/products/detail/stmicroelectronics/1N5819/1037326
1 | VR1 Option #1 Voltage regulator | LM7805_TO220 | LM7805 5V 1.5A Voltage Regulator | Standard 1.5A 5V regulator | https://www.digikey.com/en/products/detail/texas-instruments/LM7805CT-NOPB/3901929
1 | VR1 Option #2 Voltage regulator | V7805-2000R | DC DC CONVERTER 5V 10W | 5v 2A. Runs cooler with more current capacity | https://www.digikey.com/en/products/detail/cui-inc/V7805-2000R/2352147
1 | Y1 | 3.58 | 3.579545MHZ Colorburst Crystal |  | https://www.digikey.com/en/products/detail/raltron-electronics/a-3-579545-18/10271744
1 | U1 *Optional for +8v / 0 / -8v supply on expansion bus | IB0512S-W75R3 | DC DC Converter 12V 744MW |  | https://www.digikey.com/en/products/detail/mornsun-america-llc/IB0512S-W75R3/16571407
Displays
2 | LED1, LED2 | LED | 5mm LED Red Diffused |  | https://www.digikey.com/en/products/detail/sunled/XLUR12D/4745846
1 | DISP1, DISP2 * 7-segment LED | 5082-7740 | Hewlett-Packard 5082-7740 Red common cathode seven segment digital display | * Ebay or other surplus source
2 | DISP3, DISP4 * 4x7 Dot Matrix LED Display with logic driver | 5082-7340 | HP 5082-7340 Hexidecimal 4x7 Dot Matrix LED Display with logic driver | * Ebay or other surplus source
Capacitors
5 | C1, C16, C17, C18, C19 | 10uf Electrolytic | 10uf Electrolitic Radial Capacitor |  | https://www.digikey.com/en/products/detail/panasonic-electronic-components/ECA-1EM100B/2688676
1 | C2 | 1000uf Electrolytic | 1000uf Electrolytic Radial Capacitor |  | https://www.digikey.com/en/products/detail/rubycon/25PX1000MEFCT810X16/3134863
9 | C3, C4, C5, C6, C11, C14, C15, C20, C21 | 0.1uF | 100nf (0.1uf) Ceramic Capacitor |  | https://www.digikey.com/en/products/detail/kemet/C320C104K5R5TA7317/6562447
1 | C7 | 18pf | 18pf Ceramic Capacitor |  | https://www.digikey.com/en/products/detail/vishay-beyschlag-draloric-bc-components/K180J15C0GF5TL2/286458
1 | C8 | 10uf Electrolytic | 10uf Electrolitic Radial Capacitor |  | https://www.digikey.com/en/products/detail/panasonic-electronic-components/ECA-1EM100B/2688676
1 | C9 | 10nf | 10nf Ceramic Capacitor |  | https://www.digikey.com/en/products/detail/kemet/C320C103K3G5TA/6656406
1 | C10 | 330pf | 330pf Ceramic Capacitor |  | https://www.digikey.com/en/products/detail/vishay-beyschlag-draloric-bc-components/K331K15X7RF5TL2/286523
1 | C12 | 1uf Electrolytic | 1uf Electrolytic Radial Capacitor |  | https://www.digikey.com/en/products/detail/w%C3%BCrth-elektronik/860020672005/5727088
1 | C13 | 150nf | 150nf (0.15uf) Ceramic Capacitor |  | https://www.digikey.com/en/products/detail/kemet/C320C154K5R5TA/818052
Resistors
2 | R1, R2 | 330 | 330 ohm Carbon Film Resistor |  | https://www.digikey.com/en/products/detail/stackpole-electronics-inc/CF14JT330R/1741399
1 | R15 | 1K | 1 kilohm Carbon Film Resistor |  | https://www.digikey.com/en/products/detail/stackpole-electronics-inc/CF14JT1K00/1741314
2 | R26, R29 | 47K | 47 kilohm Carbon Film Resistor |  | https://www.digikey.com/en/products/detail/stackpole-electronics-inc/CF14JT47K0/1741444
1 | R28 | 200 | 200 ohm Carbon Film Resistor |  | https://www.digikey.com/en/products/detail/stackpole-electronics-inc/CF14JT200R/1741336
2 | R30, R36 | 10K | 10 kilohm Carbon Film Resistor |  | https://www.digikey.com/en/products/detail/stackpole-electronics-inc/CF14JT10K0/1741265
3 | R34, R35 | 2.2K | 2.2 kilohm Carbon Film Resistor |  | https://www.digikey.com/en/products/detail/stackpole-electronics-inc/CF14JT2K20/1741321
1 | R31, R32 | 470R | 470 ohm Carbon Film Resistor | R31 was origninally spec'd for 2.2k but shoud be 470 ohm | https://www.digikey.com/en/products/detail/stackpole-electronics-inc/CF14JT470R/1741440
1 | R33 | 1K | 1 kilohm Carbon Film Resistor |  | https://www.digikey.com/en/products/detail/stackpole-electronics-inc/CF14JT1K00/1741314
2 | RN1, RN3 | 22K | RES ARRAY 4 RES 22K OHM 5SIP |  | https://www.digikey.com/en/products/detail/bourns-inc/4605X-101-223LF/3593674
2 | RN2, RN4 | 22K | RES ARRAY 8 RES 22K OHM 9SIP |  | https://www.digikey.com/en/products/detail/bourns-inc/4609X-101-223LF/3593668
2 | RN5, RN6 *Used with onboard 7-segment LED Display option | 120 | RES ARRAY 8 RES 120 OHM 16DIP |  | https://www.digikey.com/en/products/detail/bourns-inc/4116R-1-121LF/1088613
Switches
1 | S2 | S2 | MEMORY PROTECT |  | https://www.digikey.com/en/products/detail/e-switch/100SP1T1B4M2QE/378824
1 | S3 | S3 | LOAD |  | https://www.digikey.com/en/products/detail/e-switch/100SP1T1B4M2QE/378824
1 | S4 | S4 | RUN |  | https://www.digikey.com/en/products/detail/e-switch/100SP1T1B4M2QE/378824
1 | S5 | S5 | POWER |  | https://www.digikey.com/en/products/detail/cit-relay-and-switch/ANT11TFHQE/12503364
17 | Hex Keypad + Input | SW1 - SW16 + S1 | Cherry type keyboard switch (Amazon 30 piece set) | Amazon: https://www.amazon.ca/dp/B0BXZXZX74
1 | DIP_SW1 | DIP_SW1 | 8 Position DIP Switch |  | https://www.digikey.com/en/products/detail/grayhill-inc/76SB08T/726235
Connectors
1 | J1 | Barrel Power connector | Manufacturer Product Number PJ-002BH |  | https://www.digikey.com/en/products/detail/cui-devices/PJ-002BH/408447
1 | CN1 | VIDEO OUT | Video Output Jack |  | https://www.digikey.com/en/products/detail/cui-devices/RCJ-014/408490
1 | T1 | CASSETTE OUT | Audio Jack T1 |  | https://www.digikey.com/en/products/detail/cui-devices/MJ-3536N/281264
1 | T2 | CASSETTE IN | Audio Jack T2 |  | https://www.digikey.com/en/products/detail/cui-devices/MJ-3536N/281264
5 | P1, P2, P3, P4, P5 *Black TE Connectivity AMP Connectors | Optional Expansion Sockets | 86 Position Female Connector Non Specified - Dual |  | https://www.digikey.com/en/products/detail/te-connectivity-amp-connectors/1-5530843-0/2310825
5 | P1, P2, P3, P4, P5 *Green EDAC Inc. | Optional Expansion Sockets | 86 Position Female Connector Non Specified - Dual |  | https://www.digikey.com/en/products/detail/edac-inc/345-086-520-202/1294448
4 | DM1, DM2, DM3, DM4 *Optional for Raised Daughter Card Display | J1, J2, J3, J4 | 16 pin F Dual Row Socket |  | https://www.digikey.com/en/products/detail/sullins-connector-solutions/PPPC082LFBN-RC/810248
5 | M1, M2, M3, M4, M5 * Optional For Raised Keypad | S7002-ND | 4 Position Header Connector 0.100" (2.54mm) |  | https://www.digikey.com/en/products/detail/sullins-connector-solutions/PPTC041LFBN-RC/810144
Jumpers
8 | J2, J3, J4, J7, J9, J11, J+8V1, J-8V1 |  | Connector Header Through Hole 0.100" (2.54mm) |  | https://www.digikey.com/en/products/detail/sullins-connector-solutions/PREC040SAAN-RC/2774814
Misc
2 | Triangular Wooden Side Rails |  | Veneered Wood: 2.75 inches tall, 7 inches long on the back and bottom ends with about a 1/8 inch bevel on the very front tip so it's not sharp down to a point.
1 | BATT1 | BATT | 5volt Battery Source for optional onboard battery backup for RAM

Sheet: Mouser.ca
QUANTITY | PART # | PART | DESCRIPTION | NOTES | Mouser
IC's
1 | A1 | CY62256 | SRAM 256K-Bit (32Kx8) | Jameco Electronics: https://www.jameco.com/z/HM62256LP-70-HITACHI-IC-62256LP-CMOS-SRAM-256K-Bit-32Kx8-70ns-Low-Power_82472.html | ~
1 | A2 | 74HC573 | D-Type Transparent Latch |  | https://www.mouser.ca/ProductDetail/Texas-Instruments/SN74HC573AN?qs=%252BWCn1GN4mVzruISjDLpAxw%3D%3D
2 | A3, A4 | 4016 | Bilateral, FET Switches |  | https://www.mouser.ca/ProductDetail/Texas-Instruments/CD4016BE?qs=L4Mc90zKIpgI%252B7Li46bF8Q%3D%3D
1 | A5 | 4023 | NAND Gate IC 3 Channel |  | https://www.mouser.ca/ProductDetail/Texas-Instruments/CD4023BE?qs=5h8QSfodyRgDHNYia77aew%3D%3D
1 | A6 | CDP1802ACE | RCA CMOS 8-Bit Microprocessor | * Ebay or other surplus source | ~
2 | A7, A11 | 4050 | Buffer, Non-Inverting |  | https://www.mouser.ca/ProductDetail/Texas-Instruments/CD4050BE?qs=j%2FZo4ajzVJLKLpJvKsajlg%3D%3D
1 | A8, A12 *Used with onboard 7-segment LED Display option | DM9368 | 7-Segment Decoder/Driver/Latch | * Ebay or other surplus source | ~
1 | A9 | 74C173 | Flip Flop D-Type |  | https://www.mouser.ca/ProductDetail/Texas-Instruments/CD74HC173E?qs=j01uVdFEFjELTUIKncHz%252Bg%3D%3D
1 | A10 | MM74C922 | 16-20 Key Encoder DIP 18-pin | Jameco Electronics: https://www.jameco.com/z/74C922-Major-Brands-IC-74C922-16-20-Key-Encoder-DIP-18-pin_44564.html | ~
2 | A13, A18 | 4049 | Inverter IC 6 Channel |  | https://www.mouser.ca/ProductDetail/Texas-Instruments/CD4049UBE?qs=D5pVkbrsqqLvQoWdk2gTTw%3D%3D
1 | A14 | CDP1861 | RCA Pixie Graphics Video Display Controller | * Ebay or other surplus source | ~
1 | A15 | 74LS00 | NAND Gate | * Note: This is an LS device and the clock may not operate correctly if an HC or other type of TTL device is used. | https://www.mouser.ca/ProductDetail/Texas-Instruments/SN74LS00N?qs=spW5eSrOWB6G5wECF%252BEZFA%3D%3D
1 | A16 | 74HC74 | D-Type Flip Flop | * Note: This is an HC device and the clock may not operate correctly if an LS or other type of TTL device is used. | https://www.mouser.ca/ProductDetail/Texas-Instruments/CD74HCT74E?qs=ZA235jQDfboKM%252BOEvlrfDA%3D%3D
1 | A17 | 4013 | D-Type Flip Flop |  | https://www.mouser.ca/ProductDetail/Texas-Instruments/CD4013BE?qs=pt%2FIv5r0EPc2Chv9B9JKAA%3D%3D
Semiconductors
12 | D1, D2, D5, D6, D7, D8, D9, D10, D11, D12, D13, D14 | 1N914 | Diode 100 V 200mA Through Hole DO-35 |  | https://www.mouser.ca/ProductDetail/onsemi-Fairchild/1N914B?qs=sGAEpiMZZMtbRapU8LlZDzCgIkNleXIZjCSZIvAdjSc%3D
1 | D3 | 1N4001 | Diode 50 V 1A Through Hole Axial |  | https://www.mouser.ca/ProductDetail/Comchip-Technology/1N4001-G?qs=2qJf6qQ4IOKJYZQUWvVExw%3D%3D
3 | D15, D16, D17 | 1N5819 | Schottky Diode 40V 1A |  | https://www.mouser.ca/ProductDetail/STMicroelectronics/1N5819
1 | VR1 Option #1 Voltage regulator | LM7805_TO220 | LM7805 5V 1.5A Voltage Regulator | Standard 1.5A 5V regulator | https://www.mouser.ca/ProductDetail/Texas-Instruments/LM7805CT-NOPB?qs=OYMYEaN9QmBS2GvaX6GSkQ%3D%3D
1 | VR1 Option #2 Voltage regulator | V7805-2000R | DC DC CONVERTER 5V 10W | 5v 2A. Runs cooler with more current capacity | https://www.mouser.ca/ProductDetail/CUI-Inc/V7805-2000R?qs=WyjlAZoYn51jf4NpQC3pwg%3D%3D
1 | Y1 | 3.58 | 3.579545MHZ Colorburst Crystal |  | https://www.mouser.ca/ProductDetail/ABRACON/AB-3.579545MHZ-B2?qs=A7YjigRBFZl%252BZCeHxwts5w%3D%3D
1 | U1 *Optional for +8v / 0 / -8v supply on expansion bus | IB0512S-W75R3 | DC DC Converter 12V 744MW | DigiKey: https://www.digikey.ca/en/products/detail/mornsun-america-llc/IB0512S-W75R3/16571407
Displays
2 | LED1, LED2 | LED | 5mm LED Red Diffused |  | https://www.mouser.ca/ProductDetail/Kingbright/WP7113ID?qs=hyavMCx%252BcmDJhCThgY7pfQ%3D%3D
1 | DISP1, DISP2 * 7-segment LED | 5082-7740 | Hewlett-Packard 5082-7740 Red common cathode seven segment digital display | * Ebay or other surplus source
2 | DISP3, DISP4 * 4x7 Dot Matrix LED Display with logic driver | 5082-7340 | HP 5082-7340 Hexidecimal 4x7 Dot Matrix LED Display with logic driver | * Ebay or other surplus source
Capacitors
5 | C1, C16, C17, C18, C19 | 10uf Electrolytic | 10uf Electrolytic Radial Capacitor |  | https://www.mouser.ca/ProductDetail/Panasonic/ECE-A1VKA100B
1 | C2 | 1000uf Electrolytic | 1000uf Electrolytic Radial Capacitor |  | https://www.mouser.ca/ProductDetail/Wurth-Elektronik/860020475018?qs=0KOYDY2FL29%2F2GIHZNCdMQ%3D%3D
9 | C3, C4, C5, C6, C11, C14, C15, C20, C21 | 0.1uF | 0.1uf Ceramic Capacitor |  | https://www.mouser.ca/ProductDetail/Murata-Electronics/RCER71H104K0K1H03B?qs=Zt%252BKPUOg4of53jbypBpoRQ%3D%3D
1 | C7 | 18pf | 18pf Ceramic Capacitor |  | https://www.mouser.ca/ProductDetail/Murata-Electronics/RCE5C1H180J0DBH03A?qs=Zt%252BKPUOg4oe0KImv0CLFIg%3D%3D
1 | C8 | 10uf Electrolytic | 10uf Electrolytic Radial Capacitor |  | https://www.mouser.ca/ProductDetail/Panasonic/ECE-A1VKA100B
1 | C9 | 10nf | 10nf Ceramic Capacitor |  | https://www.mouser.ca/ProductDetail/Vishay-BC-Components/K103K10X7RF5UL2?qs=8fb2TFeI5qF81ybioAo4oA%3D%3D
1 | C10 | 330pf | 330pf Ceramic Capacitor |  | https://www.mouser.ca/ProductDetail/Murata-Electronics/RCER71H331K0M1H03A?qs=Zt%252BKPUOg4od0Plr59sXaYA%3D%3D
1 | C12 | 1uf Electrolytic | 1uf Electrolytic Radial Capacitor |  | https://www.mouser.ca/ProductDetail/Wurth-Elektronik/860020672005?qs=0KOYDY2FL29w5cS8aahRvQ%3D%3D
1 | C13 | 150nf | 150nf (0.15uf) Ceramic Capacitor |  | https://www.mouser.ca/ProductDetail/Murata-Electronics/RCER71H154K1DBH03A?qs=Zt%252BKPUOg4ocsdlDaWBbrMA%3D%3D
Resistors
2 | R1, R2 | 330 | 330 ohm Carbon Film Resistor |  | https://www.mouser.ca/ProductDetail/SEI-Stackpole/CF14JT330R?qs=FESYatJ8odL8jgcbJiLESA%3D%3D
1 | R15 | 1K | 1 kilohm Carbon Film Resistor |  | https://www.mouser.ca/ProductDetail/SEI-Stackpole/CF14JT1K00?qs=FESYatJ8odLLAkjsom%2FJYQ%3D%3D
2 | R26, R29 | 47K | 47 kilohm Carbon Film Resistor |  | https://www.mouser.ca/ProductDetail/SEI-Stackpole/CF14JT47K0?qs=FESYatJ8odKVS%252BsmTHTzYw%3D%3D
1 | R28 | 200 | 200 ohm Carbon Film Resistor |  | https://www.mouser.ca/ProductDetail/SEI-Stackpole/CF14JT200R?qs=FESYatJ8odJ%2Flj3FwweRcQ%3D%3D
2 | R30, R36 | 10K | 10 kilohm Carbon Film Resistor |  | https://www.mouser.ca/ProductDetail/SEI-Stackpole/CF14JT10K0?qs=FESYatJ8odJcEE4HXxUVCA%3D%3D
3 | R34, R35 | 2.2K | 2.2 kilohm Carbon Film Resistor |  | https://www.mouser.ca/ProductDetail/SEI-Stackpole/CF14JT2K20?qs=FESYatJ8odIUhJBtuDkv0g%3D%3D
1 | R31, R32 | 470R | 470 ohm Carbon Film Resistor | R31 was origninally spec'd for 2.2k but shoud be 470 ohm | https://www.mouser.ca/ProductDetail/SEI-Stackpole/CF14JT470R?qs=FESYatJ8odKPSi5QyIvqiA%3D%3D
1 | R33 | 1K | 1 kilohm Carbon Film Resistor |  | https://www.mouser.ca/ProductDetail/SEI-Stackpole/CF14JT1K00?qs=FESYatJ8odLLAkjsom%2FJYQ%3D%3D
2 | RN1, RN3 | 22K | RES ARRAY 4 RES 22K OHM 5SIP |  | https://www.mouser.ca/ProductDetail/Bourns/4605X-101-223LF?qs=uIm7Mbr8JPUMjObm8ImyRg%3D%3D
2 | RN2, RN4 | 22K | RES ARRAY 8 RES 22K OHM 9SIP |  | https://www.mouser.ca/ProductDetail/Bourns/4609X-101-223LF?qs=9nA2MLoIC7lSuIK9u5MO%2FQ%3D%3D
2 | RN5, RN6 *Used with onboard 7-segment LED Display option | 120 | RES ARRAY 8 RES 120 OHM 16DIP |  | https://www.mouser.ca/ProductDetail/Bourns/4116R-1-121LF?qs=10P5Hhl%252BD7%2FiVs%252BU8BCs6Q%3D%3D
Switches
1 | S2 | S2 | MEMORY PROTECT |  | https://www.mouser.ca/ProductDetail/E-Switch/100SP1T1B4M2QE?qs=YXf4ACKMM4xJ0mJK%2FyIa1g%3D%3D
1 | S3 | S3 | LOAD |  | https://www.mouser.ca/ProductDetail/E-Switch/100SP1T1B4M2QE?qs=YXf4ACKMM4xJ0mJK%2FyIa1g%3D%3D
1 | S4 | S4 | RUN |  | https://www.mouser.ca/ProductDetail/E-Switch/100SP1T1B4M2QE?qs=YXf4ACKMM4xJ0mJK%2FyIa1g%3D%3D
1 | S5 | S5 | POWER
17 | Hex Keypad + Input | SW1 - SW16 + S1 | Cherry type keyboard switch (Amazon 30 piece set) | Amazon: https://www.amazon.ca/dp/B0BXZXZX74
1 | DIP_SW1 | DIP_SW1 | 8 Position DIP Switch |  | https://www.mouser.ca/ProductDetail/Grayhill/76SB08T?qs=ls7QRyWmRk5XdXgRWzYlvg%3D%3D
Connectors
1 | J1 | Barrel Power connector | Manufacturer Product Number PJ-002BH |  | https://www.mouser.ca/ProductDetail/CUI-Devices/PJ-002BH?qs=WyjlAZoYn51nOX1h%2FqpLlg%3D%3D
1 | CN1 | VIDEO OUT | Video Output Jack |  | https://www.mouser.ca/ProductDetail/CUI-Devices/RCJ-014?qs=WyjlAZoYn53hpijiyk9ZIA%3D%3D
1 | T1 | CASSETTE OUT | Audio Jack T1 |  | https://www.mouser.ca/ProductDetail/CUI-Devices/MJ-3536N?qs=WyjlAZoYn51vdgS3Tq1ykQ%3D%3D
1 | T2 | CASSETTE IN | Audio Jack T2 |  | https://www.mouser.ca/ProductDetail/CUI-Devices/MJ-3536N?qs=WyjlAZoYn51vdgS3Tq1ykQ%3D%3D
5 | P1, P2, P3, P4, P5 *Green EDAC Inc. | Optional Expansion Sockets | 86 Position Female Connector Non Specified - Dual |  | https://www.mouser.ca/ProductDetail/EDAC/345-086-520-202?qs=kP3P12TjBhsTrfJpP98Y5A%3D%3D
4 | DM1, DM2, DM3, DM4 *Optional for Raised Daughter Card Display | J1, J2, J3, J4 | 16 pin F Dual Row Socket | DigiKey: https://www.digikey.ca/en/products/detail/sullins-connector-solutions/PPPC082LFBN-RC/810248
5 | M1, M2, M3, M4, M5 * Optional For Raised Keypad | S7002-ND | 4 Position Header Connector 0.100" (2.54mm) |  | https://www.mouser.ca/ProductDetail/TE-Connectivity/2314878-4?qs=P1JMDcb91o7WkCUv19Mivg%3D%3D
Jumpers
8 | J2, J3, J4, J7, J9, J11, J+8V1, J-8V1 |  | Connector Header Through Hole 0.100" (2.54mm) |  | https://www.mouser.ca/ProductDetail/Amphenol-FCI/68691-440HLF?qs=cPwqfQhQFYMYN3UF9G02MQ%3D%3D
Misc
2 | Triangular Wooden Side Rails |  | Veneered Wood: 2.75 inches tall, 7 inches long on the back and bottom ends with about a 1/8 inch bevel on the very front tip so it's not sharp down to a point.
1 | BATT1 | BATT | 5volt Battery Source for optional onboard battery backup for RAM
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

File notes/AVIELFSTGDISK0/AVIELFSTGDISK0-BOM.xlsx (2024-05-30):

QUANTITY | PART # | PART | DESCRIPTION | NOTES | DIGIKEY
IC Sockets
1 | 40-PIN Socket DIP |  | 40 (2 x 20) Pos DIP, 0.6" (15.24mm) Row Spacing Socket Through Hole
2 | 28-PIN Socket DIP |  | 28 (2 x 14) Pos DIP, 0.6" (15.24mm) Row Spacing Socket Through Hole
1 | 24-PIN Socket DIP |  | 24 (2 x 12) Pos DIP, 0.6" (15.24mm) Row Spacing Socket Through Hole
2 | 20-PIN DIP Socket |  | 20 (2 x 10) Pos DIP, 0.3" (7.62mm) Row Spacing Socket Through Hole
3 | 16-PIN DIP Socket |  | 16 (2 x 8) Pos DIP, 0.3" (7.62mm) Row Spacing Socket Through Hole
7 | 14-PIN DIP Socket |  | 14 (2 x 7) Pos DIP, 0.3" (7.62mm) Row Spacing Socket Through Hole
IC's
1 | U1 | 74HC139 | 74xx:74LS139 | Package_DIP:DIP-16_W7.62mm
1 | U2 | 74HC245 | 74xx:74HC245 | Package_DIP:DIP-20_W7.62mm
1 | U3 | 74HC174 | 74xx:74LS174 | Package_DIP:DIP-16_W7.62mm
1 | U4 | DS12887A | 1_Josh_lib:DS12887A | Package_DIP:DIP-24_W15.24mm
1 | U5 | FT232RL | Interface_USB:FT232RL | Package_SO:SSOP-28_5.3x10.2mm_P0.65mm | https://www.digikey.ca/en/products/detail/ftdi-future-technology-devices-international-ltd/FT232RL-TUBE/4006920
1 | U6 | 74HC11 | 74xx:74LS11 | Package_DIP:DIP-14_W7.62mm | https://www.digikey.ca/en/products/detail/texas-instruments/SN74HC11N/376871
1 | U7 | 16450 | Interface_UART:16450 | Package_DIP:DIP-40_W15.24mm
1 | U8 | 74HC04 | 74xx:74LS04 | Package_DIP:DIP-14_W7.62mm
1 | U9 | 74HC573 | 74xx:74LS573 | Package_DIP:DIP-20_W7.62mm
1 | U10 | CY62256-70PC | Memory_RAM:CY62256-70PC | Package_DIP:DIP-28_W15.24mm
1 | U11 | 28C256 | Memory_EEPROM:28C256 | Package_DIP:DIP-28_W15.24mm
2 | U12, U13 | 74HC00 | 74xx:74LS00 | Package_DIP:DIP-14_W7.62mm
1 | U14 | 74HC02 | 74xx:74LS02 | Package_DIP:DIP-14_W7.62mm
1 | U15 | 74HC74 | 74xx:74HC74 | Package_DIP:DIP-14_W7.62mm
1 | U16 | 74HC04 | 74xx:74HC04 | Package_DIP:DIP-14_W7.62mm
1 | U17 | MAX232 | Interface_UART:MAX232 | Package_DIP:DIP-16_W7.62mm | https://www.digikey.ca/en/products/detail/texas-instruments/MAX232N/277048
Semiconductors
4 | D1 - D4 | 1N914 | Diode:1N914 | Diode_THT:D_DO-35_SOD27_P7.62mm_Horizontal
1 | Q1 | 2N3906 | Transistor_BJT:2N3906 | Package_TO_SOT_THT:TO-92_Inline
1 | Y1 | 2.4576Mhz | Device:Crystal | Crystal:Crystal_HC18-U_Horizontal
Displays
8 | D5 - D12 |  | Device:LED
Capacitors
2 | C1, C2 | 22p | Device:C | Capacitor_THT:C_Disc_D3.0mm_W1.6mm_P2.50mm
5 | C3, C4, C5, C6, C7 | 1uF | Device:C_Polarized_Small_US | Capacitor_THT:CP_Radial_Tantal_D4.5mm_P2.50mm
13 | C8 - C20 | 0.1 | Device:C | Capacitor_THT:C_Disc_D3.0mm_W1.6mm_P2.50mm
2 | C21, C22 | 10uF | Device:C_Polarized_US | Capacitor_THT:CP_Radial_Tantal_D5.0mm_P2.50mm
Resistors
1 | R1 | 10M | Device:R | Resistor_THT:R_Axial_DIN0207_L6.3mm_D2.5mm_P7.62mm_Horizontal
6 | R2, R3, R4, R5, R6, R7 | 4.7K | Device:R | Resistor_THT:R_Axial_DIN0207_L6.3mm_D2.5mm_P7.62mm_Horizontal
1 | RN1 | 470 | Device:R_Network08 | Resistor_THT:R_Array_SIP9
Jumpers
1 | J3 | Conn_02x10_Odd_Even | Connector_Generic:Conn_02x10_Odd_Even | Connector_PinHeader_2.54mm:PinHeader_2x10_P2.54mm_Vertical | ~
2 | J7, J8 | Conn_01x06_Socket | Connector:Conn_01x06_Socket | Connector_PinHeader_2.54mm:PinHeader_1x06_P2.54mm_Vertical | ~
1 | JP1 | DISK IRQ | Jumper:Jumper_2_Bridged | Connector_PinHeader_2.54mm:PinHeader_1x02_P2.54mm_Vertical | ~
1 | JP2 | RTC IRQ | Jumper:Jumper_2_Bridged | Connector_PinHeader_2.54mm:PinHeader_1x02_P2.54mm_Vertical | ~
1 | JP3 | UART IRQ | Jumper:Jumper_2_Bridged | Connector_PinHeader_2.54mm:PinHeader_1x02_P2.54mm_Vertical | ~
1 | JP4 | CF SEL | Jumper:Jumper_2_Bridged | Connector_PinHeader_2.54mm:PinHeader_1x02_P2.54mm_Vertical | ~
1 | JP5 | RTC CLR | Jumper:Jumper_2_Bridged | Connector_PinHeader_2.54mm:PinHeader_1x02_P2.54mm_Vertical | ~
1 | JP6 | BOOT | Jumper:Jumper_3_Open | Connector_PinHeader_2.54mm:PinHeader_1x03_P2.54mm_Vertical | ~
1 | JP7 | EEPROM | Connector_Generic:Conn_02x03_Odd_Even | Connector_PinHeader_2.54mm:PinHeader_2x03_P2.54mm_Vertical | ~
1 | JP8 | +5V | Jumper:Jumper_2_Bridged | Connector_PinHeader_2.54mm:PinHeader_1x02_P2.54mm_Vertical | ~
1 | JP9 | FTDI RESET | Jumper:Jumper_2_Bridged | Connector_PinHeader_2.54mm:PinHeader_1x02_P2.54mm_Vertical | ~
2 | JP10, JP11 | 5 | Jumper:Jumper_2_Bridged | Connector_PinHeader_2.54mm:PinHeader_1x02_P2.54mm_Vertical | ~
1 | JP12 | RAM | Jumper:Jumper_2_Bridged | Connector_PinHeader_2.54mm:PinHeader_1x02_P2.54mm_Vertical | ~
1 | JP13 | ROM | Jumper:Jumper_2_Bridged | Connector_PinHeader_2.54mm:PinHeader_1x02_P2.54mm_Vertical | ~
Misc
1 | J2 | 3M157509-ND | 3M N7E50-M516RB-40 50 Position Card Connector CompactFlash® - Type I, II Surface Mount, Right Angle Gold |  | https://www.digikey.ca/en/products/detail/3m/N7E50-M516RB-40/1092038
1 | J4 | 40PIN | Connector_Generic:Conn_02x20_Odd_Even | Connector_PinHeader_2.54mm:PinHeader_2x20_P2.54mm_Vertical | ~
1 | J5 | 151-1206-1-ND | Connector:USB_B_Micro | 1_Josh_lib:MiniSD | https://www.digikey.ca/en/products/detail/edac-inc/690-005-299-043/4312191
1 | J6 | DE9_Receptacle | Connector:DE9_Receptacle | Connector_Dsub:DSUB-9_Female_Horizontal_P2.77x2.84mm_EdgePinOffset9.90mm_Housed_MountingHolesOffset11.32mm | https://www.digikey.ca/en/products/detail/assmann-wsw-components/A-DF-09-A-KG-T2S/1241800

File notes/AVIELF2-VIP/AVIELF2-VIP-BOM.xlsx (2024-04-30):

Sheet: Digikey.ca
QTY | PART # | PART | DESCRIPTION | NOTES | DIGIKEY
IC's
1 | U1 | CD4515B | 4-Bit Latched/4-to-16 Line Decoders | Not in stock at DigiKey or Mouser. Limited supply at Jameco: https://www.jameco.com/webapp/wcs/stores/servlet/ProductDisplay?productId=2290471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
1 | U2 | CD4512BE | Data Selector/Multiplexer 1 x 8:1 16-PDIP |  | https://www.digikey.ca/en/products/detail/texas-instruments/CD4512BE/67343
1 | U3 | NE555 | 555 Type, Timer/Oscillator (Single) IC 100kHz 8-PDIP |  | https://www.digikey.ca/en/products/detail/texas-instruments/NE555P/277057
Semiconductors
1 | Q1 | 2N3906 | Bipolar (BJT) Transistor PNP 40 V 200 mA 250MHz Through Hole TO-92 |  | https://www.digikey.ca/en/products/detail/comchip-technology/2N3906-G/9477908
1 | D1 | /Q LED | 5mm LED Diffused: Red |  | https://www.digikey.ca/en/products/detail/liteon/LTL2R3KRD-EM/2675133
3 | D2, D3, D4 | 1N914 | Diode 100 V 200mA Through Hole DO-35 |  | https://www.digikey.ca/en/products/detail/onsemi/1N914/978749 | D | 1=K 2=A
Capacitors
3 | C1, C2, C3 | 0.1uf | 0.1uf Ceramic Capacitor |  | https://www.digikey.ca/en/products/detail/kemet/C320C104K5R5TA7317/6562447
1 | C4 | 470pF | 470pF Ceramic Capacitor |  | https://www.digikey.ca/en/products/detail/vishay-beyschlag-draloric-bc-components/K471K15X7RH53L2/2823135
1 | C5 | 4.7uF | Electrolytic Radial Capacitor |  | https://www.digikey.ca/en/products/detail/panasonic-electronic-components/ECA-1HM4R7/245036
1 | C6 | 2.2uF | Electrolytic Radial Capacitor |  | https://www.digikey.ca/en/products/detail/panasonic-electronic-components/ECA-1HM2R2/245034
1 | C7 | 22uF | Electrolytic Radial Capacitor |  | https://www.digikey.ca/en/products/detail/panasonic-electronic-components/ECA-1EM220I/2688679
1 | C8 | 10uF | Electrolytic Radial Capacitor |  | https://www.digikey.ca/en/products/detail/panasonic-electronic-components/ECA-1EM100B/2688676
Resistors
1 | R1 | 330 | 330 Ohms Carbon Film Resistor |  | https://www.digikey.ca/en/products/detail/stackpole-electronics-inc/CF14JT330R/1741399
1 | R2, R8 | 10K | 10 kOhms Carbon Film Resistor |  | https://www.digikey.ca/en/products/detail/stackpole-electronics-inc/CF14JT10K0/1741265
1 | R3 | 750K | 750 kOhms Carbon Film Resistor |  | https://www.digikey.ca/en/products/detail/stackpole-electronics-inc/CF14JT750K/1741503
1 | R4 | 1K | 1 kOhms Carbon Film Resistor |  | https://www.digikey.ca/en/products/detail/stackpole-electronics-inc/CF14JT1K00/1741314
2 | R5, R7 | 4.7K | 4.7 kOhms Carbon Film Resistor |  | https://www.digikey.ca/en/products/detail/stackpole-electronics-inc/CF14JT4K70/1741428
1 | R6 | 10 | 10 Ohms Carbon Film Resistor |  | https://www.digikey.ca/en/products/detail/stackpole-electronics-inc/CF14JT10R0/1741276
Audio
1 | SPKR1 | 3949-OWS-131845LA-8D-ND | 8 Ohms Microspeaker Speaker 1 W 10 Hz ~ 10 kHz |  | https://www.digikey.ca/en/products/detail/ole-wolff-electronics-inc/OWS-131845LA-8D/17636884
Switches
16 | SW1 - SW16 | Keyswitches 0 - F | Cherry type keyboard switch (Amazon 30 piece set) | Amazon: https://www.amazon.ca/dp/B0BXZXZX74
Connectors
4 | DM1, DM2, DM3, DM4, J1, J2 | Dual row header strip | Cut strip to number of conductors required | Connector Header Through Hole 80 position 0.100" (2.54mm) | https://www.digikey.ca/en/products/detail/adam-tech/PH2-80-UA/9830504
1 | JP1 | Single row header strip | Cut strip to number of conductors required | Connector Header Through Hole 0.100" (2.54mm) | https://www.digikey.ca/en/products/detail/sullins-connector-solutions/PREC040SAAN-RC/2774814

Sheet: Digikey.com
QTY | PART # | PART | DESCRIPTION | NOTES | DIGIKEY
IC's
1 | U1 | CD4515B | 4-Bit Latched/4-to-16 Line Decoders | Not in stock at DigiKey or Mouser. Limited supply at Jameco: https://www.jameco.com/webapp/wcs/stores/servlet/ProductDisplay?productId=2290471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
1 | U2 | CD4512BE | Data Selector/Multiplexer 1 x 8:1 16-PDIP |  | https://www.digikey.com/en/products/detail/texas-instruments/CD4512BE/67343
1 | U3 | NE555 | 555 Type, Timer/Oscillator (Single) IC 100kHz 8-PDIP |  | https://www.digikey.com/en/products/detail/texas-instruments/NE555P/277057
Semiconductors
1 | Q1 | 2N3906 | Bipolar (BJT) Transistor PNP 40 V 200 mA 250MHz Through Hole TO-92 |  | https://www.digikey.com/en/products/detail/comchip-technology/2N3906-G/9477908
1 | D1 | /Q LED | 5mm LED Diffused: Red |  | https://www.digikey.com/en/products/detail/liteon/LTL2R3KRD-EM/2675133
3 | D2, D3, D4 | 1N914 | Diode 100 V 200mA Through Hole DO-35 |  | https://www.digikey.com/en/products/detail/onsemi/1N914/978749 | D | 1=K 2=A
Capacitors
3 | C1, C2, C3 | 0.1uf | 0.1uf Ceramic Capacitor |  | https://www.digikey.com/en/products/detail/kemet/C320C104K5R5TA7317/6562447
1 | C4 | 470pF | 470pF Ceramic Capacitor |  | https://www.digikey.com/en/products/detail/vishay-beyschlag-draloric-bc-components/K471K15X7RH53L2/2823135
1 | C5 | 4.7uF | Electrolytic Radial Capacitor |  | https://www.digikey.com/en/products/detail/panasonic-electronic-components/ECA-1HM4R7/245036
1 | C6 | 2.2uF | Electrolytic Radial Capacitor |  | https://www.digikey.com/en/products/detail/panasonic-electronic-components/ECA-1HM2R2/245034
1 | C7 | 22uF | Electrolytic Radial Capacitor |  | https://www.digikey.com/en/products/detail/panasonic-electronic-components/ECA-1EM220I/2688679
1 | C8 | 10uF | Electrolytic Radial Capacitor |  | https://www.digikey.com/en/products/detail/panasonic-electronic-components/ECA-1EM100B/2688676
Resistors
1 | R1 | 330 | 330 Ohms Carbon Film Resistor |  | https://www.digikey.com/en/products/detail/stackpole-electronics-inc/CF14JT330R/1741399
1 | R2, R8 | 10K | 10 kOhms Carbon Film Resistor |  | https://www.digikey.com/en/products/detail/stackpole-electronics-inc/CF14JT10K0/1741265
1 | R3 | 750K | 750 kOhms Carbon Film Resistor |  | https://www.digikey.com/en/products/detail/stackpole-electronics-inc/CF14JT750K/1741503
1 | R4 | 1K | 1 kOhms Carbon Film Resistor |  | https://www.digikey.com/en/products/detail/stackpole-electronics-inc/CF14JT1K00/1741314
2 | R5, R7 | 4.7K | 4.7 kOhms Carbon Film Resistor |  | https://www.digikey.com/en/products/detail/stackpole-electronics-inc/CF14JT4K70/1741428
1 | R6 | 10 | 10 Ohms Carbon Film Resistor |  | https://www.digikey.com/en/products/detail/stackpole-electronics-inc/CF14JT10R0/1741276
Audio
1 | SPKR1 | 3949-OWS-131845LA-8D-ND | 8 Ohms Microspeaker Speaker 1 W 10 Hz ~ 10 kHz |  | https://www.digikey.com/en/products/detail/ole-wolff-electronics-inc/OWS-131845LA-8D/17636884
Switches
16 | SW1 - SW16 | Keyswitches 0 - F | Cherry type keyboard switch (Amazon 30 piece set) | Amazon: https://www.amazon.ca/dp/B0BXZXZX74
Connectors
4 | DM1, DM2, DM3, DM4, J1, J2 | Dual row header strip | Cut strip to number of conductors required | Connector Header Through Hole 80 position 0.100" (2.54mm) | https://www.digikey.com/en/products/detail/adam-tech/PH2-80-UA/9830504
1 | JP1 | Single row header strip | Cut strip to number of conductors required | Connector Header Through Hole 0.100" (2.54mm) | https://www.digikey.com/en/products/detail/sullins-connector-solutions/PREC040SAAN-RC/2774814
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

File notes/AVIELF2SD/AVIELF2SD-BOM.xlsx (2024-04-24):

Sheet: DIGIKEY.CA
QUANTITY | PART # | PART | DESCRIPTION | NOTES | DIGIKEY
IC's
1 | U1 | L78L33_TO92 | Linear Voltage Regulator IC Positive Fixed 1 Output 100mA TO-92-3 |  | https://www.digikey.ca/en/products/detail/stmicroelectronics/L78L33ABZ-AP/1663442
1 | U9 | MAX232 | 2/2 Transceiver Full RS232 16-PDIP |  | https://www.digikey.ca/en/products/detail/texas-instruments/MAX232N/277048
1 | U14 | 27C256 | CMOS UV Erasable Programmable ROM | Not available at Digikey in errasable format. Recommend Jameco: https://www.jameco.com/z/MX27C256DC-15-Macronix-IC-27C256-15-EPROM-256K-Bit-150ns-CMOS-UV-Erasable-Prommable-ROM_39714.html
1 | U15 | 628128 | Memory_RAM:628128_DIP32_SSOP32 | * Ebay or other surplus source http://www.futurlec.com/Datasheet/Memory/628128.pdf
1 | U6 | CD4051 | Single 8-Channel Analog Multiplexer or Demultiplexer with Logic-Level Conversion |  | https://www.digikey.ca/en/products/detail/texas-instruments/CD4051BE/67305
1 | U10 | 74HC00 | Quad NAND Gate |  | https://www.digikey.ca/en/products/detail/texas-instruments/SN74HC00N/277209
1 | U4 | 74HC04 | Inverter IC 6 Channel 14-DIP |  | https://www.digikey.ca/en/products/detail/toshiba-semiconductor-and-storage/TC74HC04APF/870457
1 | U3 | 74HC27 | NOR Gate IC 3 Channel 14-PDIP |  | https://www.digikey.ca/en/products/detail/texas-instruments/SN74HC27N/476055
1 | U17 | 74HC30 | NAND Gate IC 1 Channel 8-In 14-PDIP |  | https://www.digikey.ca/en/products/detail/texas-instruments/CD74HC30E/376837
1 | U2 | 74HC32 | OR Gate IC 4 Channel 14-PDIP |  | https://www.digikey.ca/en/products/detail/texas-instruments/CD74HC32E/475930
1 | U5 | 74HC74 | Dual D-Type Positive-Edge-Triggered Flip-Flop |  | https://www.digikey.ca/en/products/detail/texas-instruments/SN74HC74N/277248
1 | U8 | 74HC157 | Multiplexer 4 x 2:1 16-PDIP |  | https://www.digikey.ca/en/products/detail/texas-instruments/CD74HC157E/1506689
1 | U12 | 74HC238 | Decoder/Demultiplexer 1 x 3:8 16-PDIP |  | https://www.digikey.ca/en/products/detail/texas-instruments/CD74HC238E/1506865
1 | U7 | 74LS259 | D-Type, Addressable 1 Channel 1:8 IC Standard 16-PDIP |  | https://www.digikey.ca/en/products/detail/texas-instruments/SN74LS259BN/563027
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

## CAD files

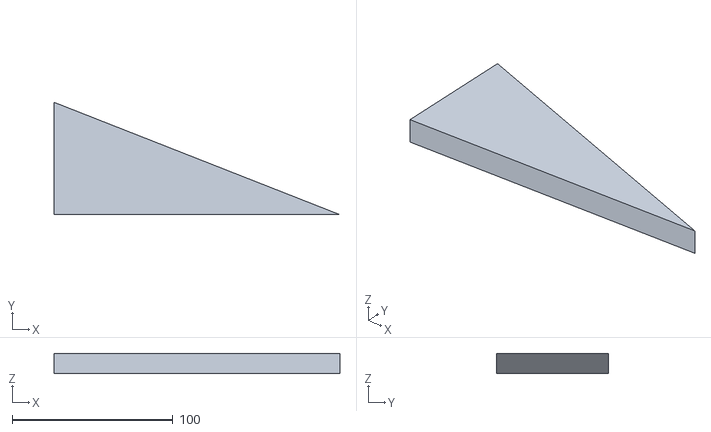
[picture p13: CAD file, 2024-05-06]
notes/ELF-II/ELF_VIP_II_Triangle.stl
177.8 x 69.9 x 12.7

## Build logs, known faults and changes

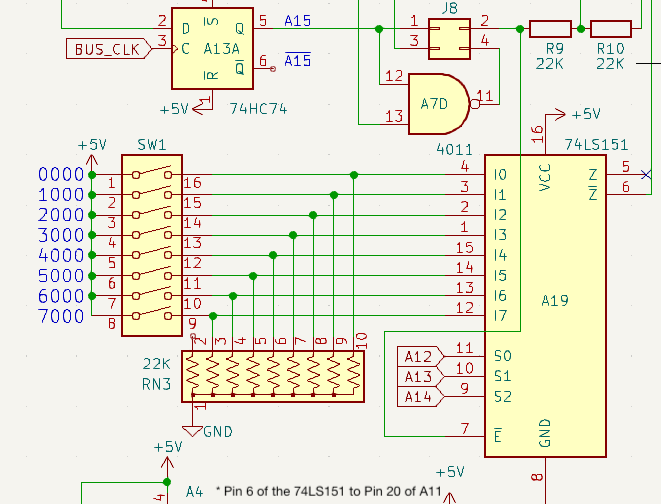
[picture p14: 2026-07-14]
notes/Hyperboard/Josh-memory-select-fix-for-hyperboard.png

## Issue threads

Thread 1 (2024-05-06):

Source for 86-pin edge connectors?

ralphw, 2024-05-06:

awasson, 2024-05-06:
Lines 69/70 in the BOM spreadsheet under Digikey, which is linked on the main page and in the Wiki Assembly Manual. The more expensive Green ones line 69 of the spreadsheet are period correct and probably the better choice. The less expensive alternative is also available at Mouser on the Mouser page in the BOM.

ralphw, 2024-05-06:
Thanks!

awasson, 2024-05-06:
Your welcome. Any time!

Closed 2024-05-06.

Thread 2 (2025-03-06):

What about the surface mount VIP?

genetoye, 2025-03-06:
Sorry to use the issues to ask this question.  Are gerbers for the surface mount VIP that Ed did available as well?  Thanks!

awasson, 2025-03-06:
No problem at all.

I am not sure what's going on with Ed's SMD VIP project. You might want to check in the Cosmac ELF Group to see or the Facebook 1802 group. I'll do some digging and post back if I can find any info.

https://groups.io/g/cosmacelf (go to messages)

https://www.facebook.com/groups/cosmacelf/

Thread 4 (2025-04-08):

VIP Keyboard - Discrepancies between Gerber file, BOM,  and Assembly Instructions

diadempro, 2025-04-08:
The Gerber file for the VIP keyboard produces what appears to be a newer revision of the board than what is shown in the assembly instructions and pictures,  There are several more diodes, resistors, jumpers, and a few layout changes.

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

This is a picture of my board, with assembly in progress.  Note places for 3 1N914 diodes (D2, D3, and D4), which is correct in BOM but assembly instructions only show and refer to one diode.

There is an additional resistor on my board - R8 - which is in the BOM, but not in the assembly instructions.

The orientation of U2 changed in my board.

Jumpers is more confusing yet - Both the assembly instructions and my board have JP1, a 3 pin jumper.  And the BOM only refers to JP1.  But the assembly instructions also show J1, which seems to be a group of 3 2-pin jumpers labeled EF4, EF3, and EF2.  And then on my board, there is an additional group J2, also labeled EF4, EF3, and EF2.

The assembly instructions also do not contain a direct link to the schematic diagram, so you have to navigate to a different page to get to it.  I believe the schematic matches my board, as it contains R8, as well as both J1 and J2 with EF2, EF3, and EF4.

I'm not clear on what settings the jumpers should have - is that explained anywhere?

diadempro, 2025-04-08:
Also a minor note... both the board in the assembly instructions, and this newer revision of the board that I appear to have, both show Dec 14, 2023 as the date stamped on the board.  Should the Gerber be updated with a newer date to avoid confusion?

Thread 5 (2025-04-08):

Added capacitors on AVI Elf II

diadempro, 2025-04-08:
There is a discrepancy between assembly instructions, and latest Gerber files of the board (and BOM), for the Electrolytic capacitors, for the AVI Elf II.  Assembly instructions step 12 refers to only 4 electrolytic caps - C1, C2, C8 and C12.

Board and BOM have 4 added C16-C19.  My board shows places to mount them per this image:

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

awasson, 2025-04-15:
Thanks Nathan,
I'll make some updates to the docs to note that.

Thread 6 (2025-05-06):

R31 needs to be 2.2K, not 470 Ohm?

diadempro, 2025-05-06:
I was having difficulty getting a stable clock.  I tried all the suggestions in note notes section of the detailed assembly guide, including the possible changes for R30, 36 and C10.  However my divider is a 74HC74, not LS, so I went back to the BOM values.

At someone's suggestion however, I changed R31 from 470 Ohm to 2.2k, and now the output of the 7474 is stable, good 1.79 MHZ clock on pin 1 of both 1802 and 1861.

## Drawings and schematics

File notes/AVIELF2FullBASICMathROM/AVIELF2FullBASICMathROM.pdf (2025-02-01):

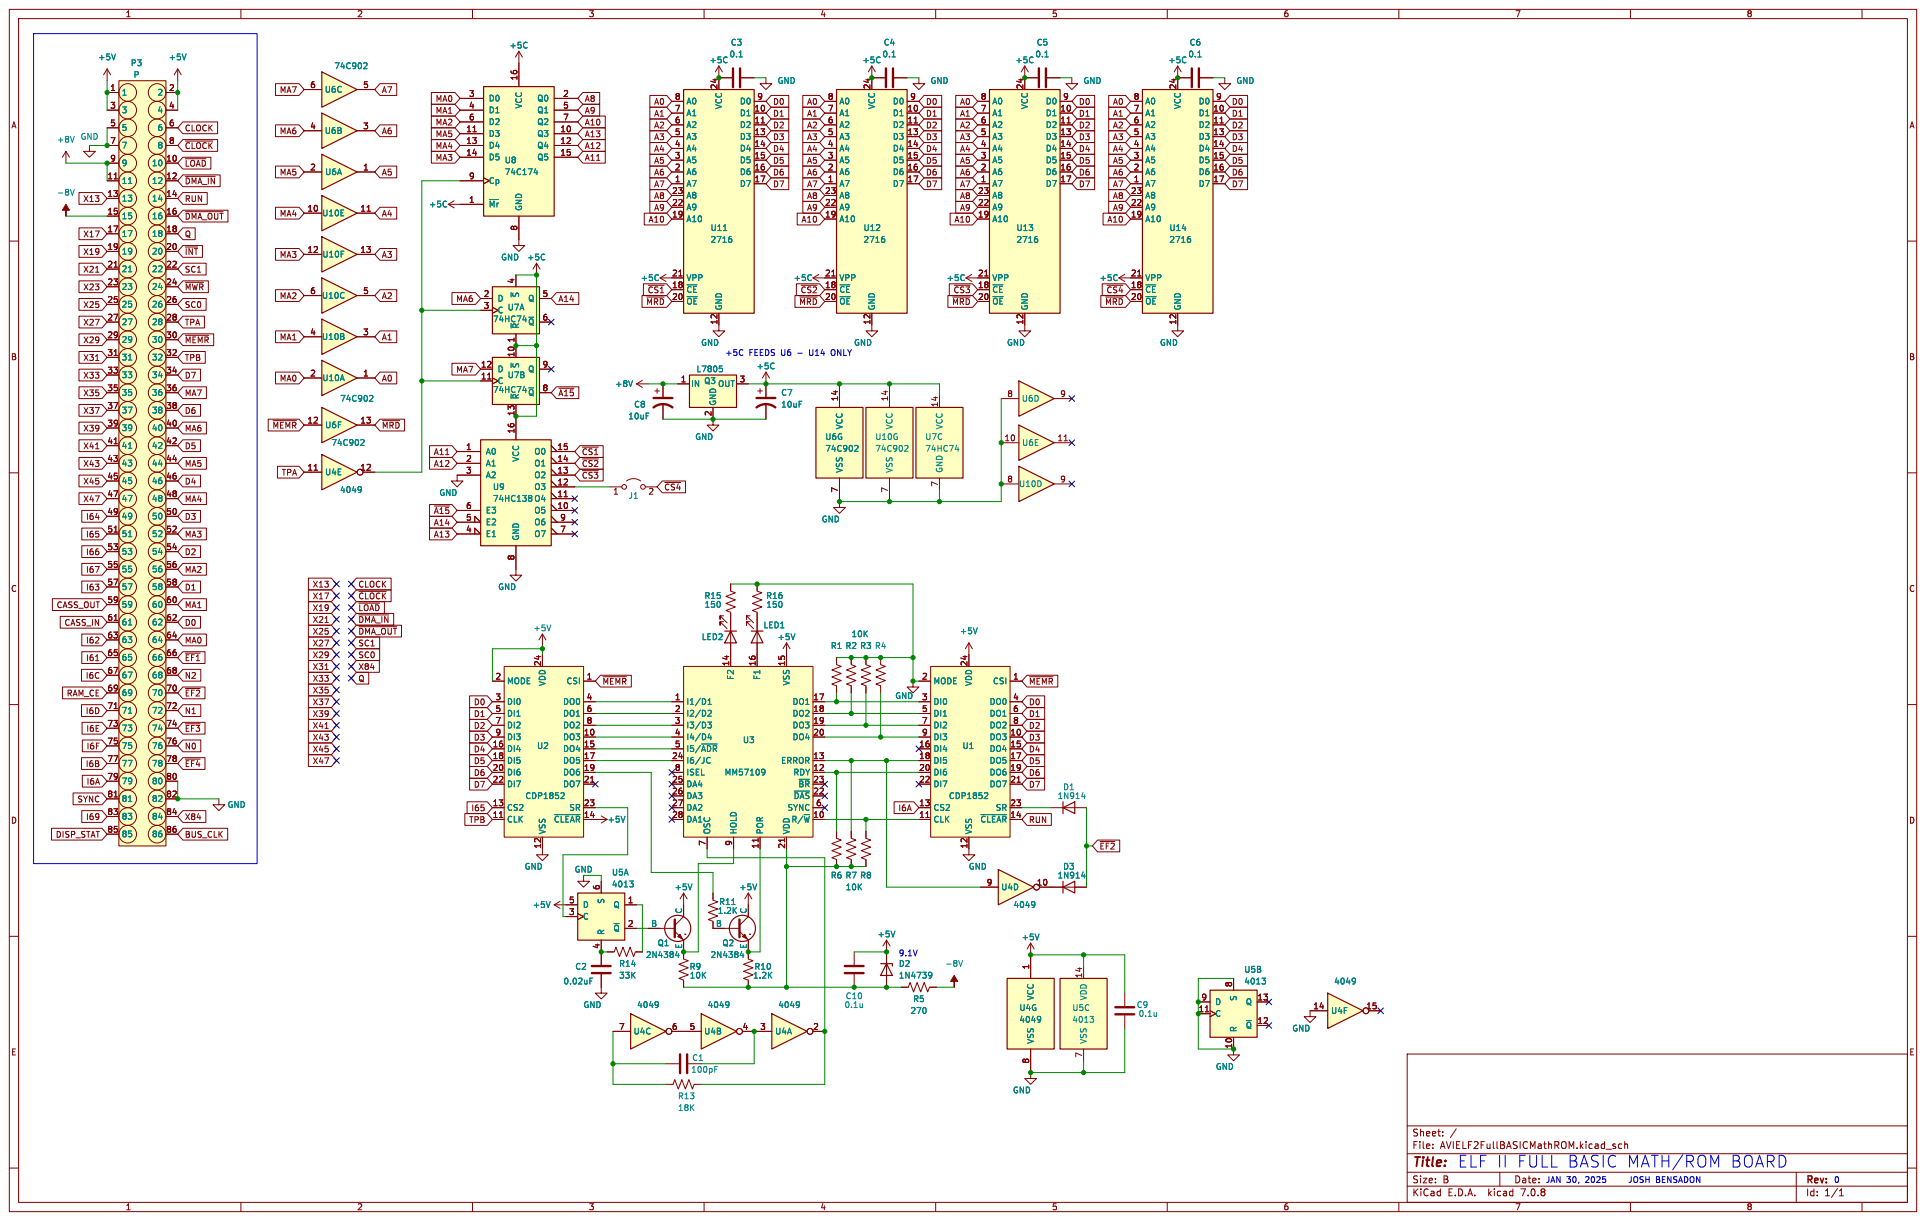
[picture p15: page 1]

Id: 1/1 Title: File: AVIELF2FullBASICMathROM.kicad_sch Sheet: /
JAN 30, 2025 ELF II FULL BASIC MATH/ROM BOARD

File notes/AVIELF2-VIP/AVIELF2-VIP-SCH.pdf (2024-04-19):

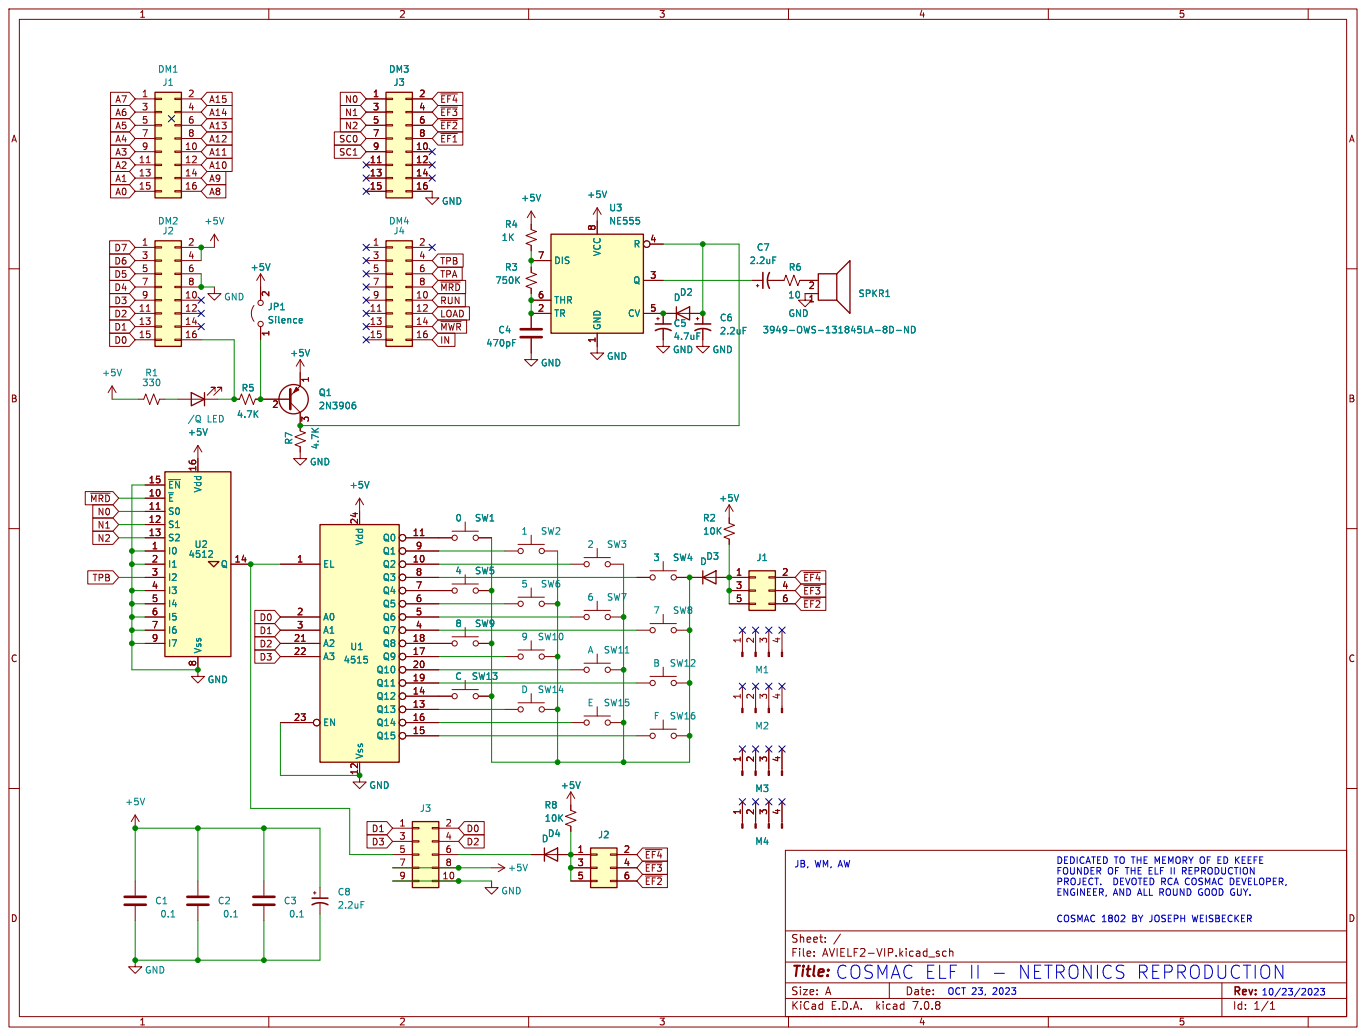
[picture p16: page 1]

DEDICATED TO THE MEMORY OF ED KEEFE
FOUNDER OF THE ELF II REPRODUCTION

PROJECT. DEVOTED RCA COSMAC DEVELOPER, ENGINEER, AND ALL ROUND GOOD GUY. JB, WM, AW

Id: 1/1 Title: File: AVIELF2-VIP.kicad_sch Sheet: /

10/23/2023 COSMAC 1802 BY JOSEPH WEISBECKER OCT 23, 2023 COSMAC ELF II - NETRONICS REPRODUCTION

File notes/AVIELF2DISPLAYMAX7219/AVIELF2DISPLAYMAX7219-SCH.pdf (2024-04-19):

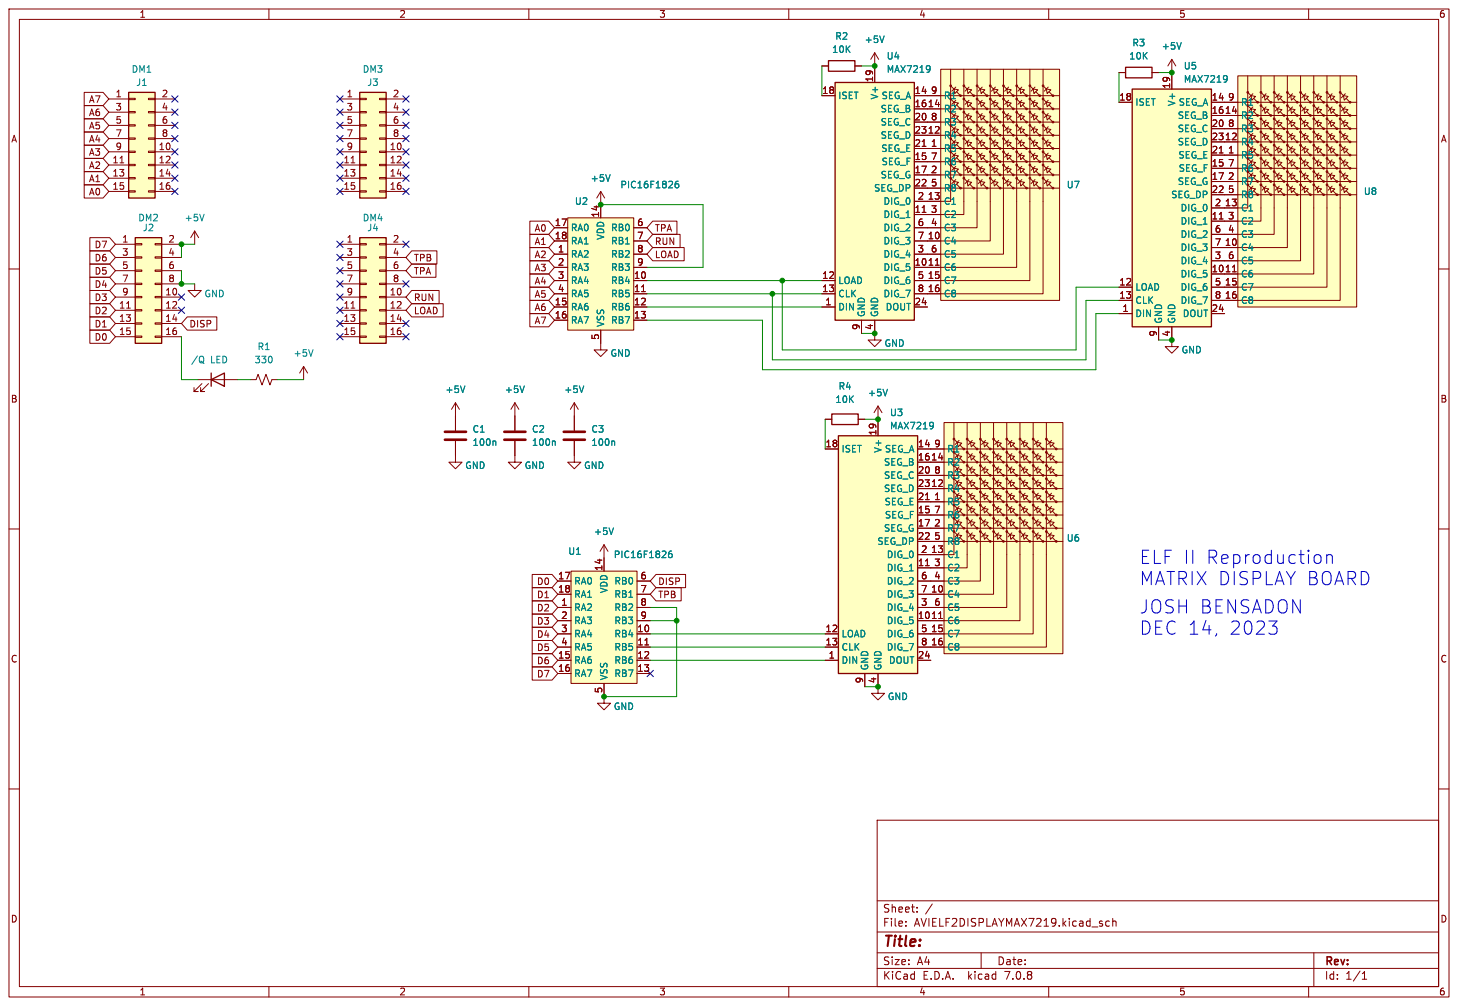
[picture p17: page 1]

Id: 1/1 Title: File: AVIELF2DISPLAYMAX7219.kicad_sch Sheet: /

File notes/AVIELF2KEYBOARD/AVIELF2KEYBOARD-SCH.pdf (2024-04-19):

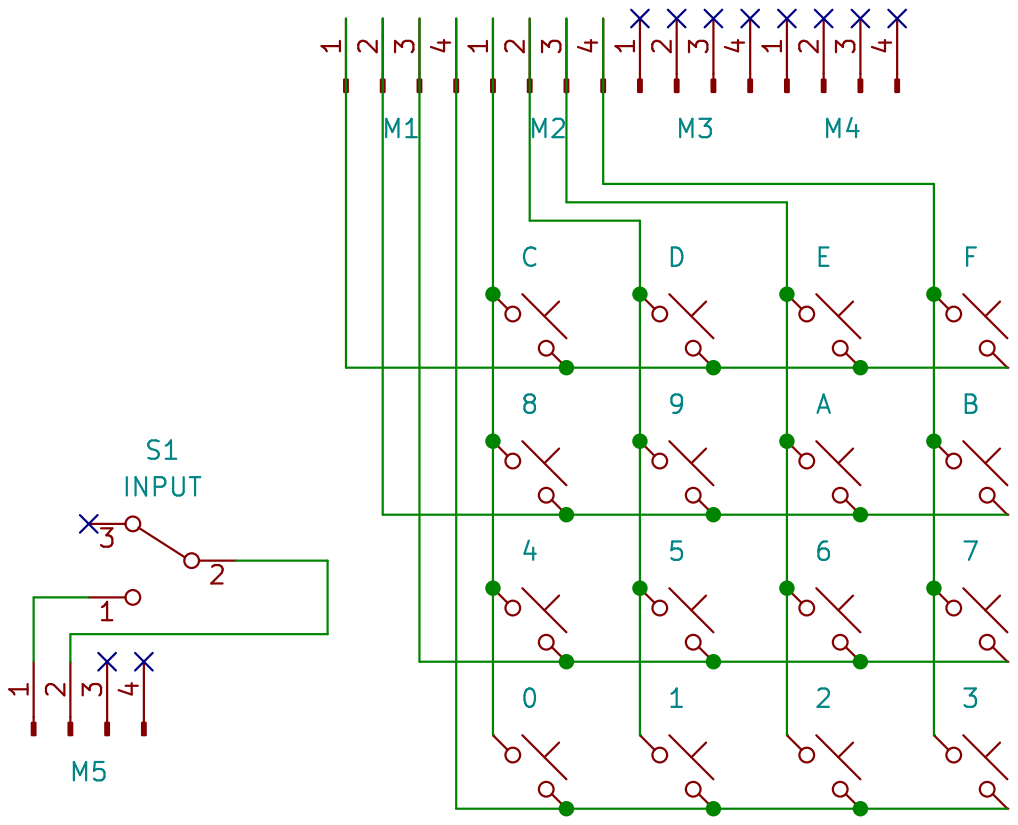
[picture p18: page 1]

Id: 1/1 Title: File: AVIELF2KEYBOARD.kicad_sch Sheet: /

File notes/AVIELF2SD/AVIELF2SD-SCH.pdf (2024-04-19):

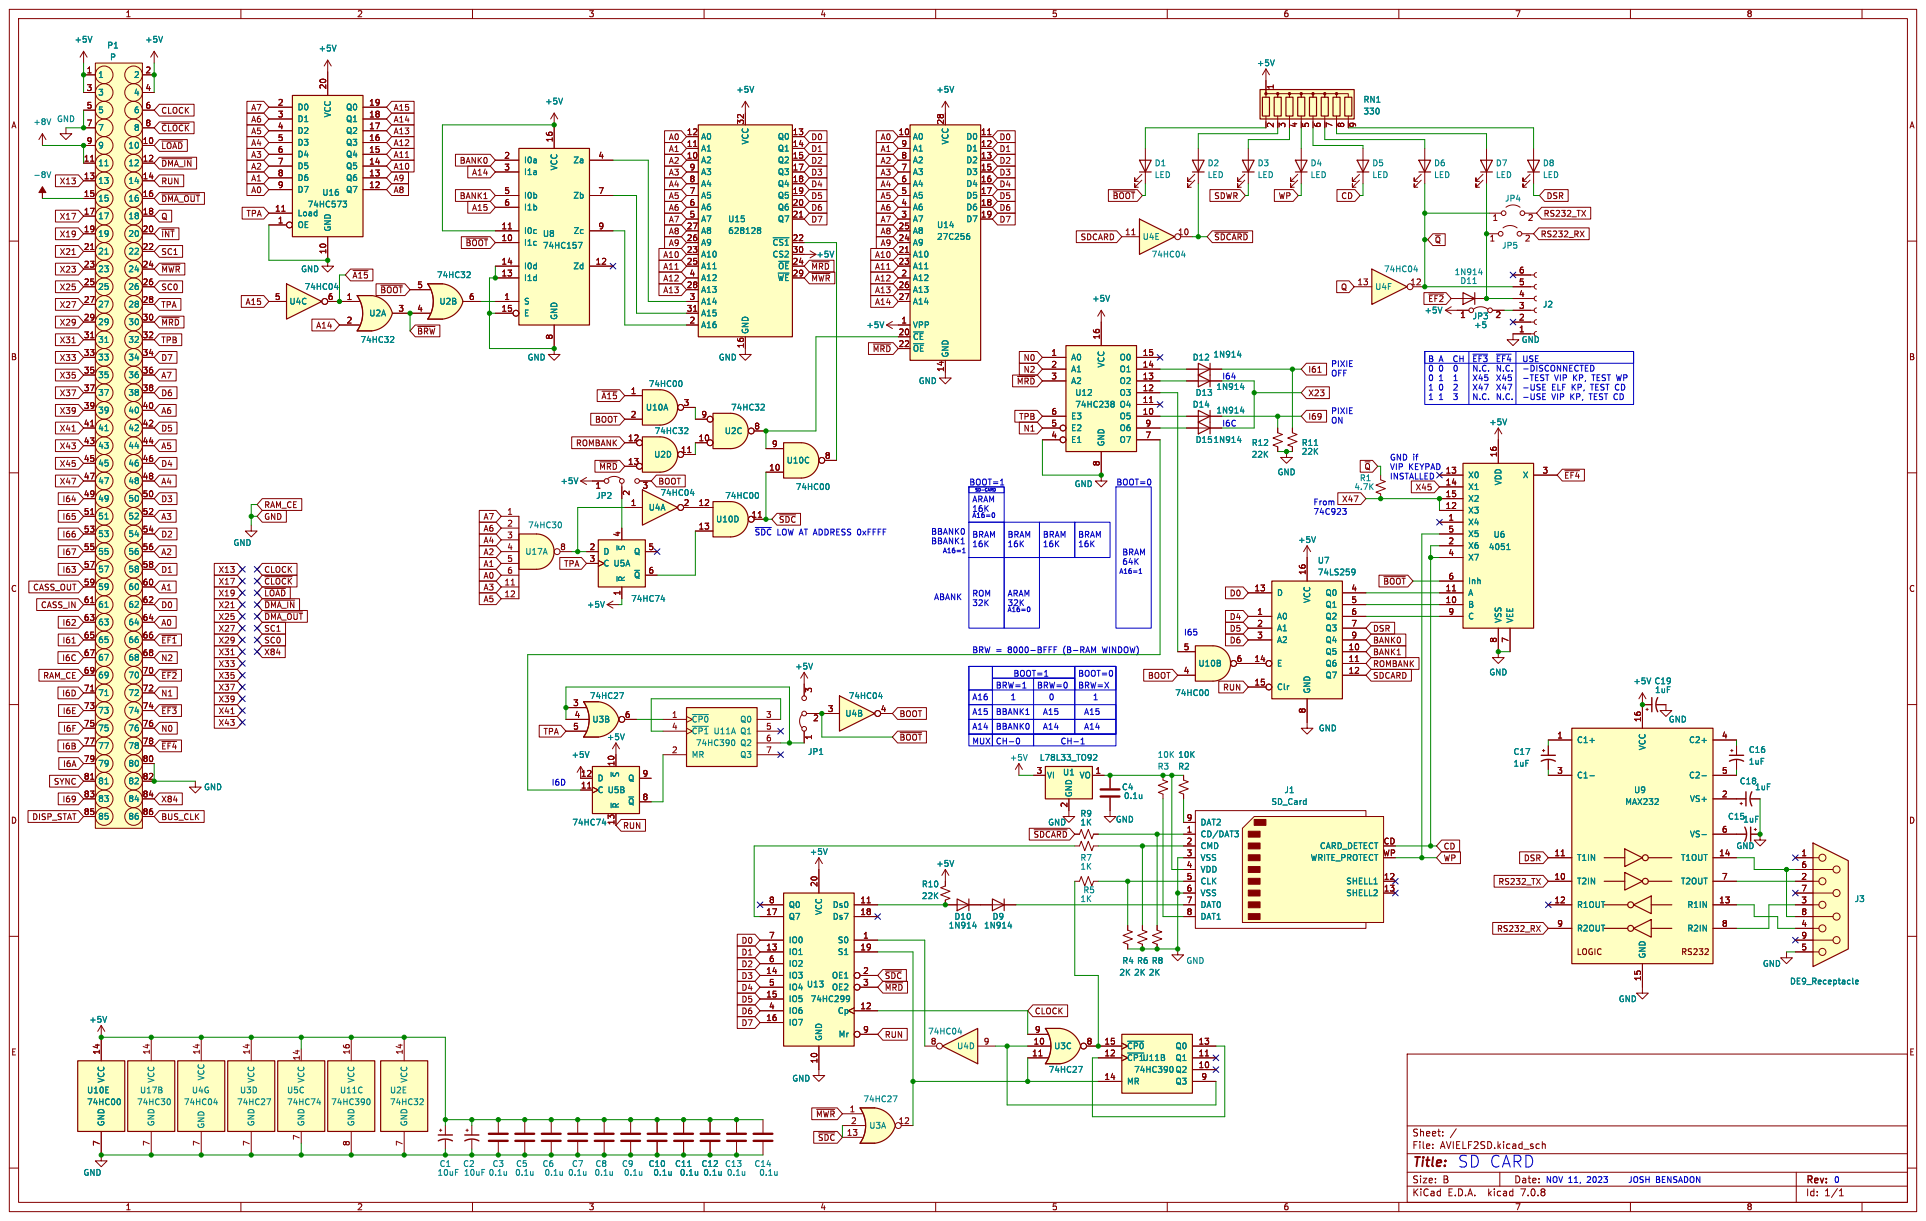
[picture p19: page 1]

-DISCONNECTED
-TEST VIP KP, TEST WP
-USE ELF KP, TEST CD
-USE VIP KP, TEST CD
+5V GND

A16=1 ~{SDC}LOW AT ADDRESS 0xFFFF

Id: 1/1 Title: File: AVIELF2SD.kicad_sch Sheet: /

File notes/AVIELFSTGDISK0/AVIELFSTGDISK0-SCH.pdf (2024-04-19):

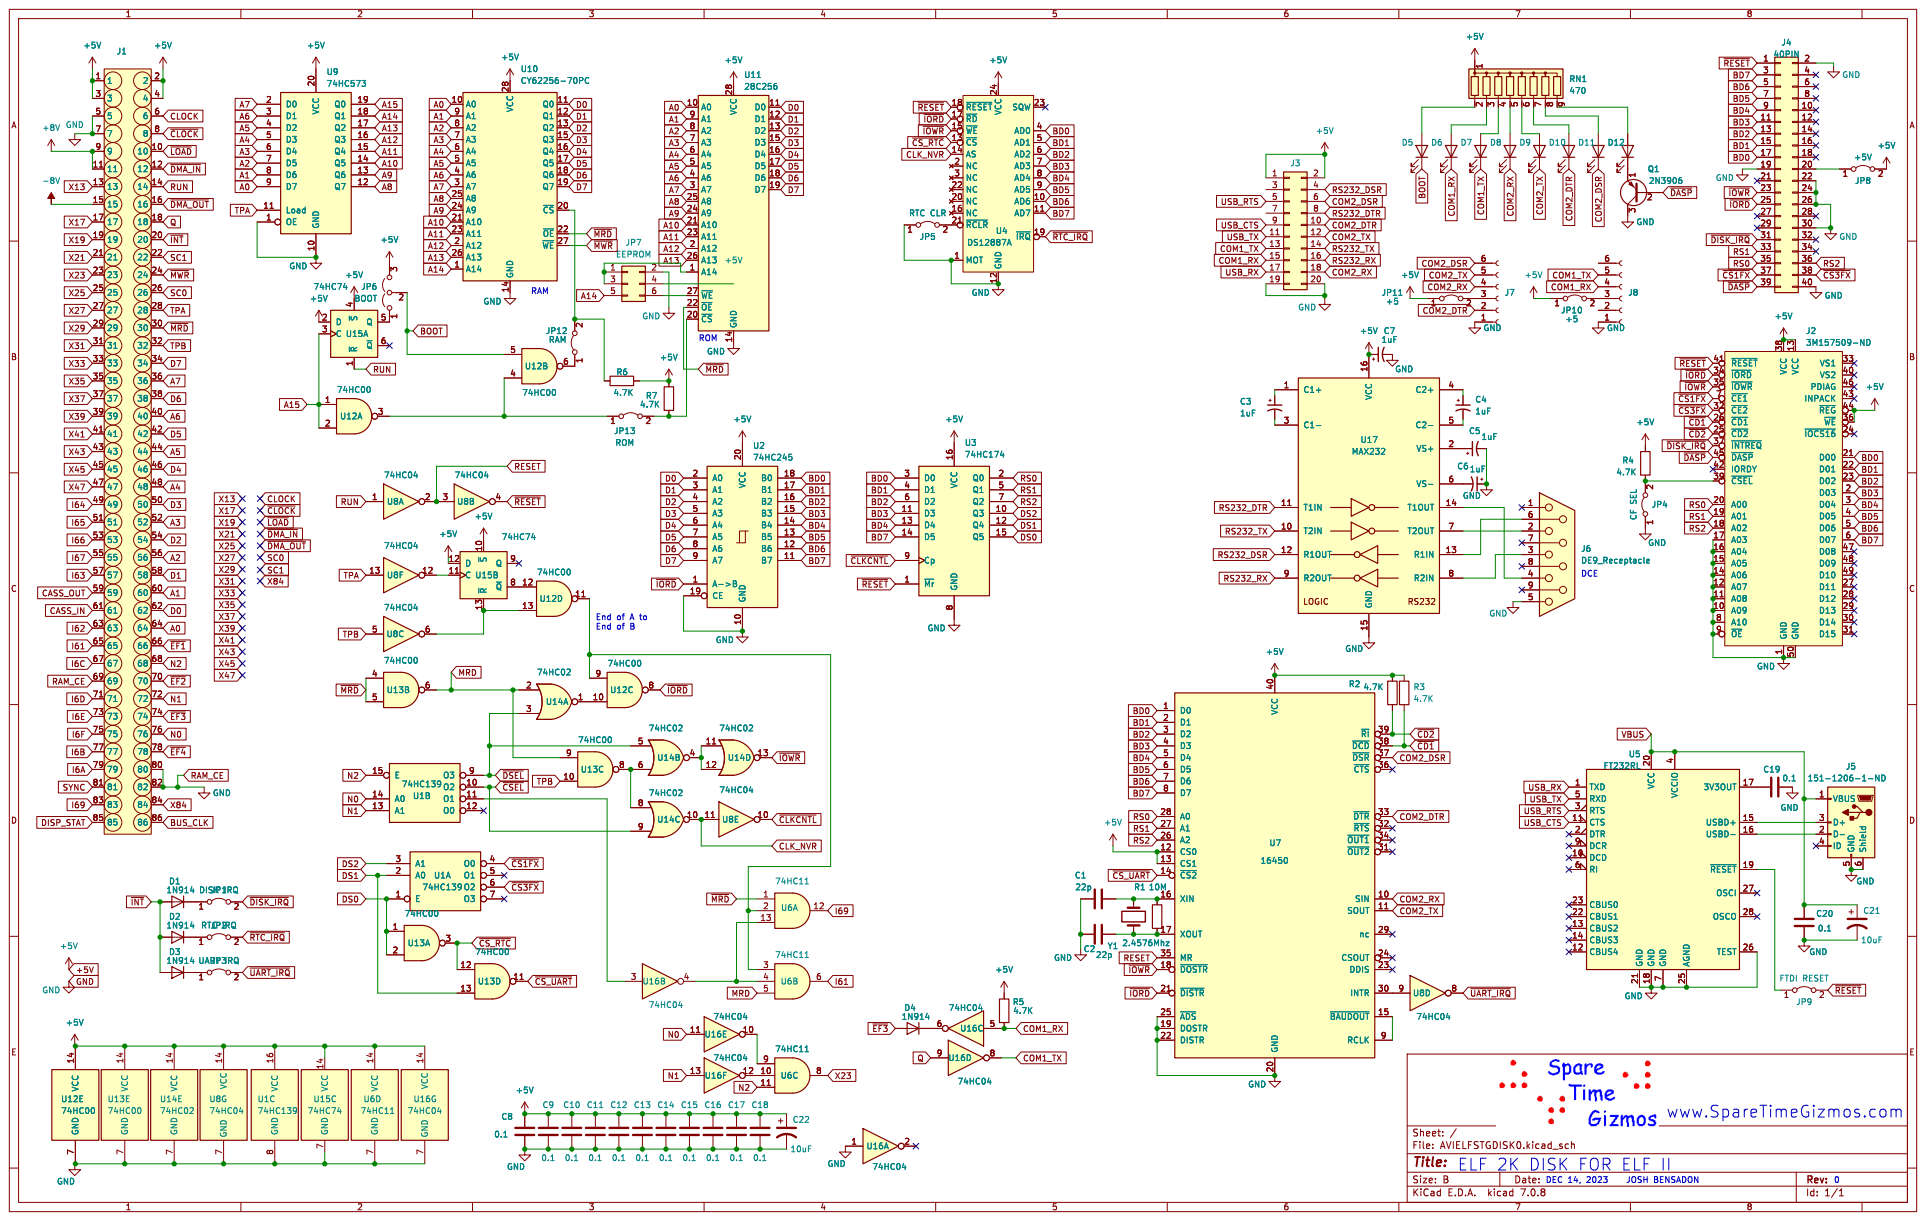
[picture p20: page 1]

End of A to End of B

Id: 1/1 Title: File: AVIELFSTGDISK0.kicad_sch Sheet: /

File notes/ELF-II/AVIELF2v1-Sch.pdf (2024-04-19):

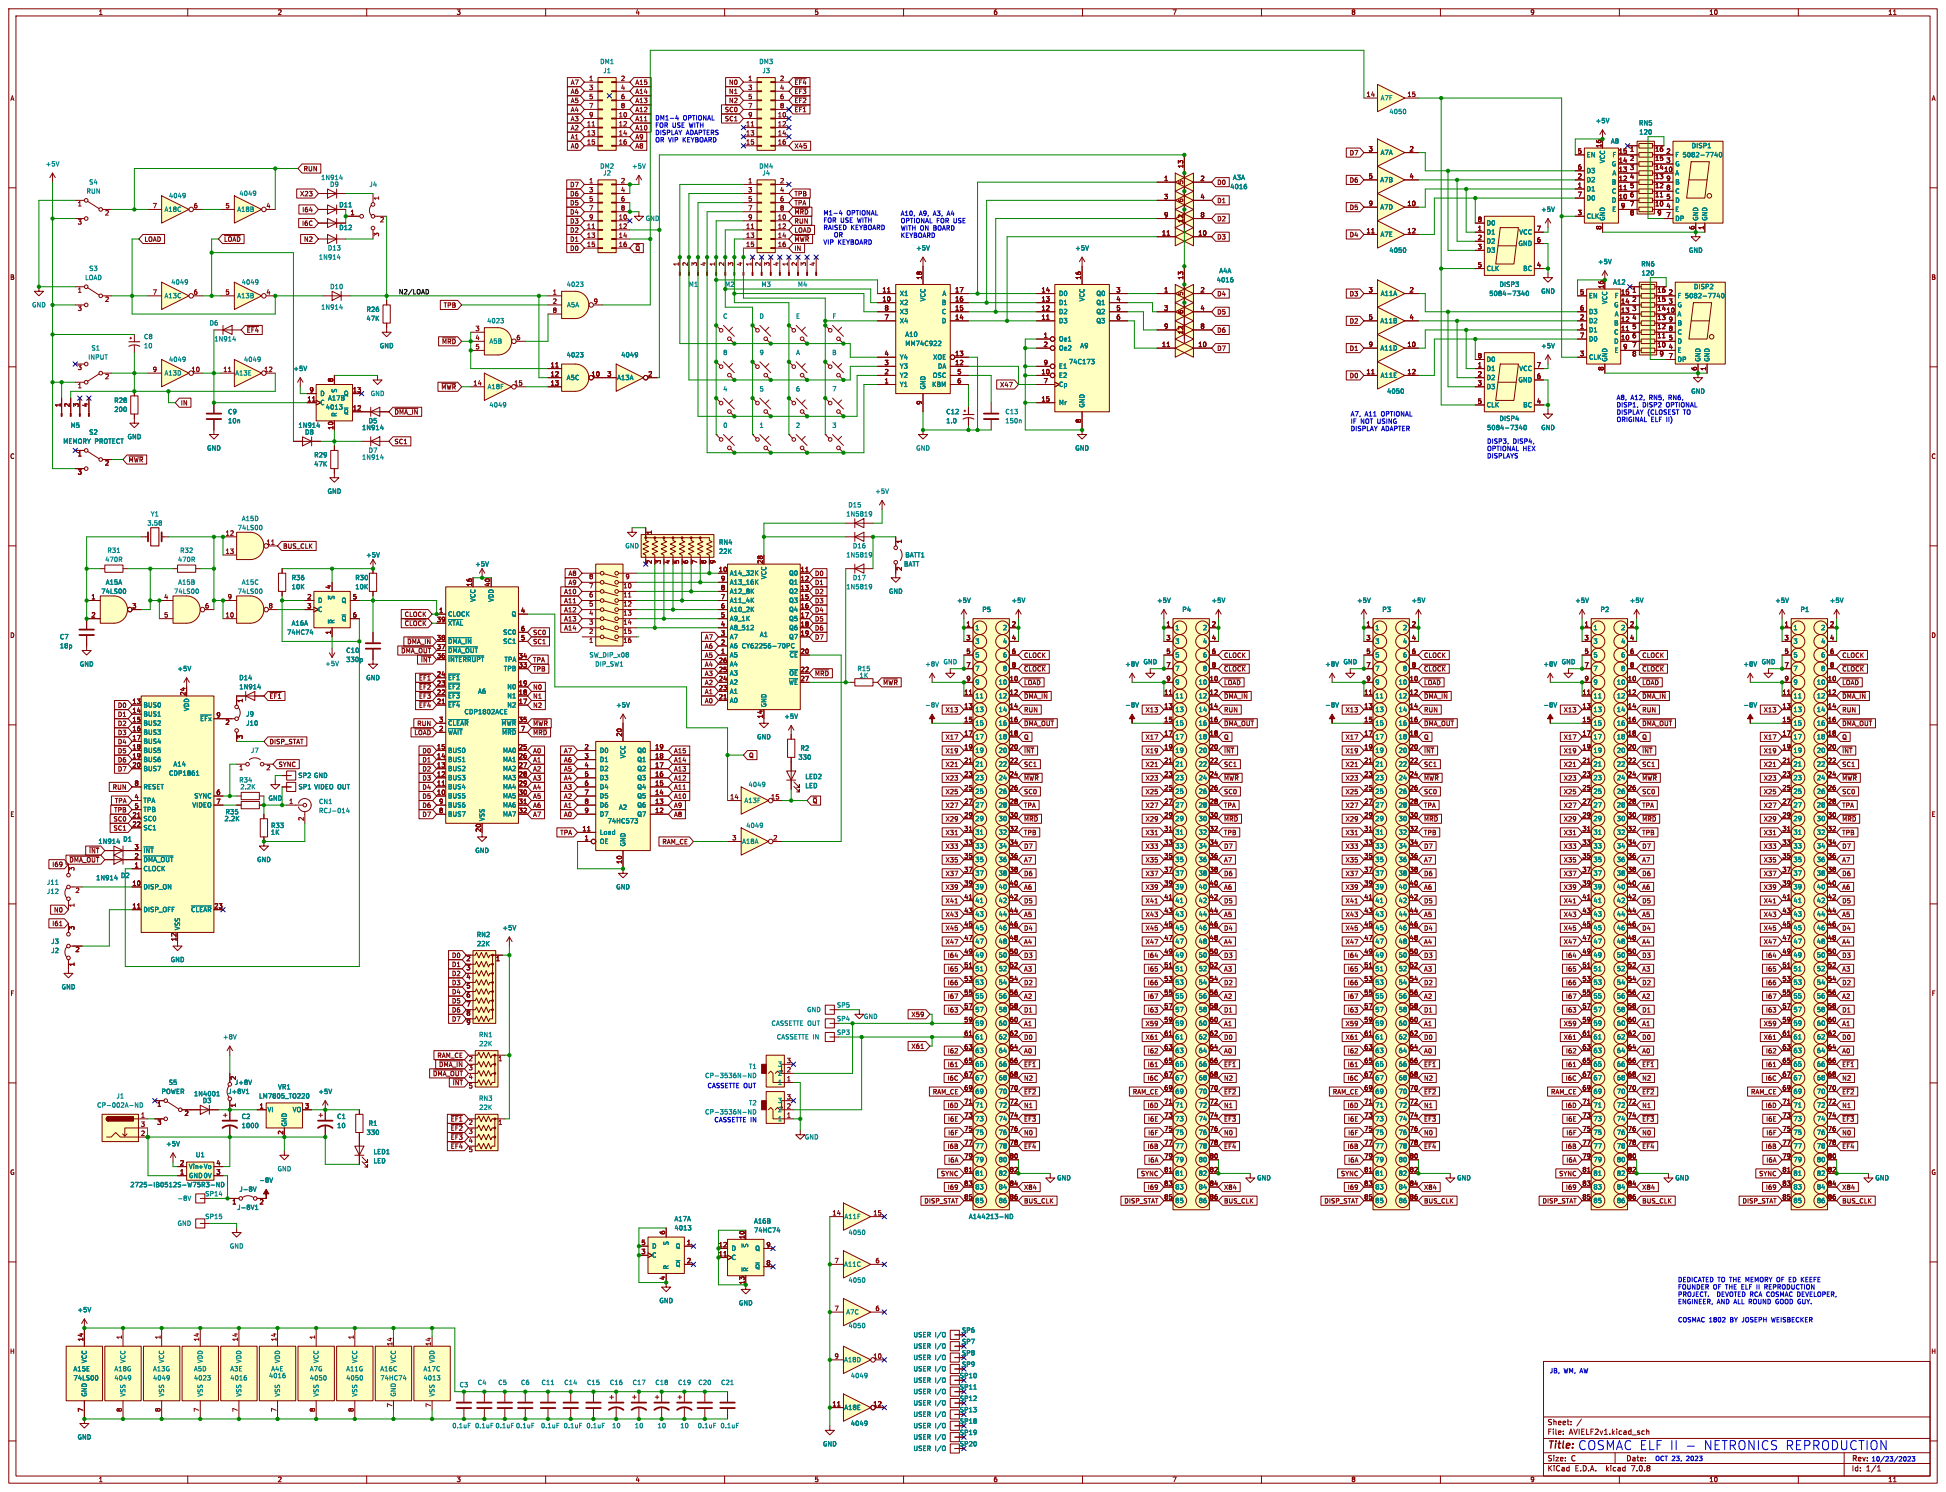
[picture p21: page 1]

A10, A9, A3, A4 OPTIONAL FOR USE WITH ON BOARD

A8, A12, RN5, RN6, DISP1, DISP2 OPTIONAL DISPLAY (CLOSEST TO

CASSETTE OUT CASSETTE IN

10/23/2023 DEDICATED TO THE MEMORY OF ED KEEFE
FOUNDER OF THE ELF II REPRODUCTION
PROJECT. DEVOTED RCA COSMAC DEVELOPER, ENGINEER, AND ALL ROUND GOOD GUY.

OCT 23, 2023 COSMAC 1802 BY JOSEPH WEISBECKER

JB, WM, AW COSMAC ELF II - NETRONICS REPRODUCTION

Id: 1/1 Title: File: AVIELF2v1.kicad_sch Sheet: /

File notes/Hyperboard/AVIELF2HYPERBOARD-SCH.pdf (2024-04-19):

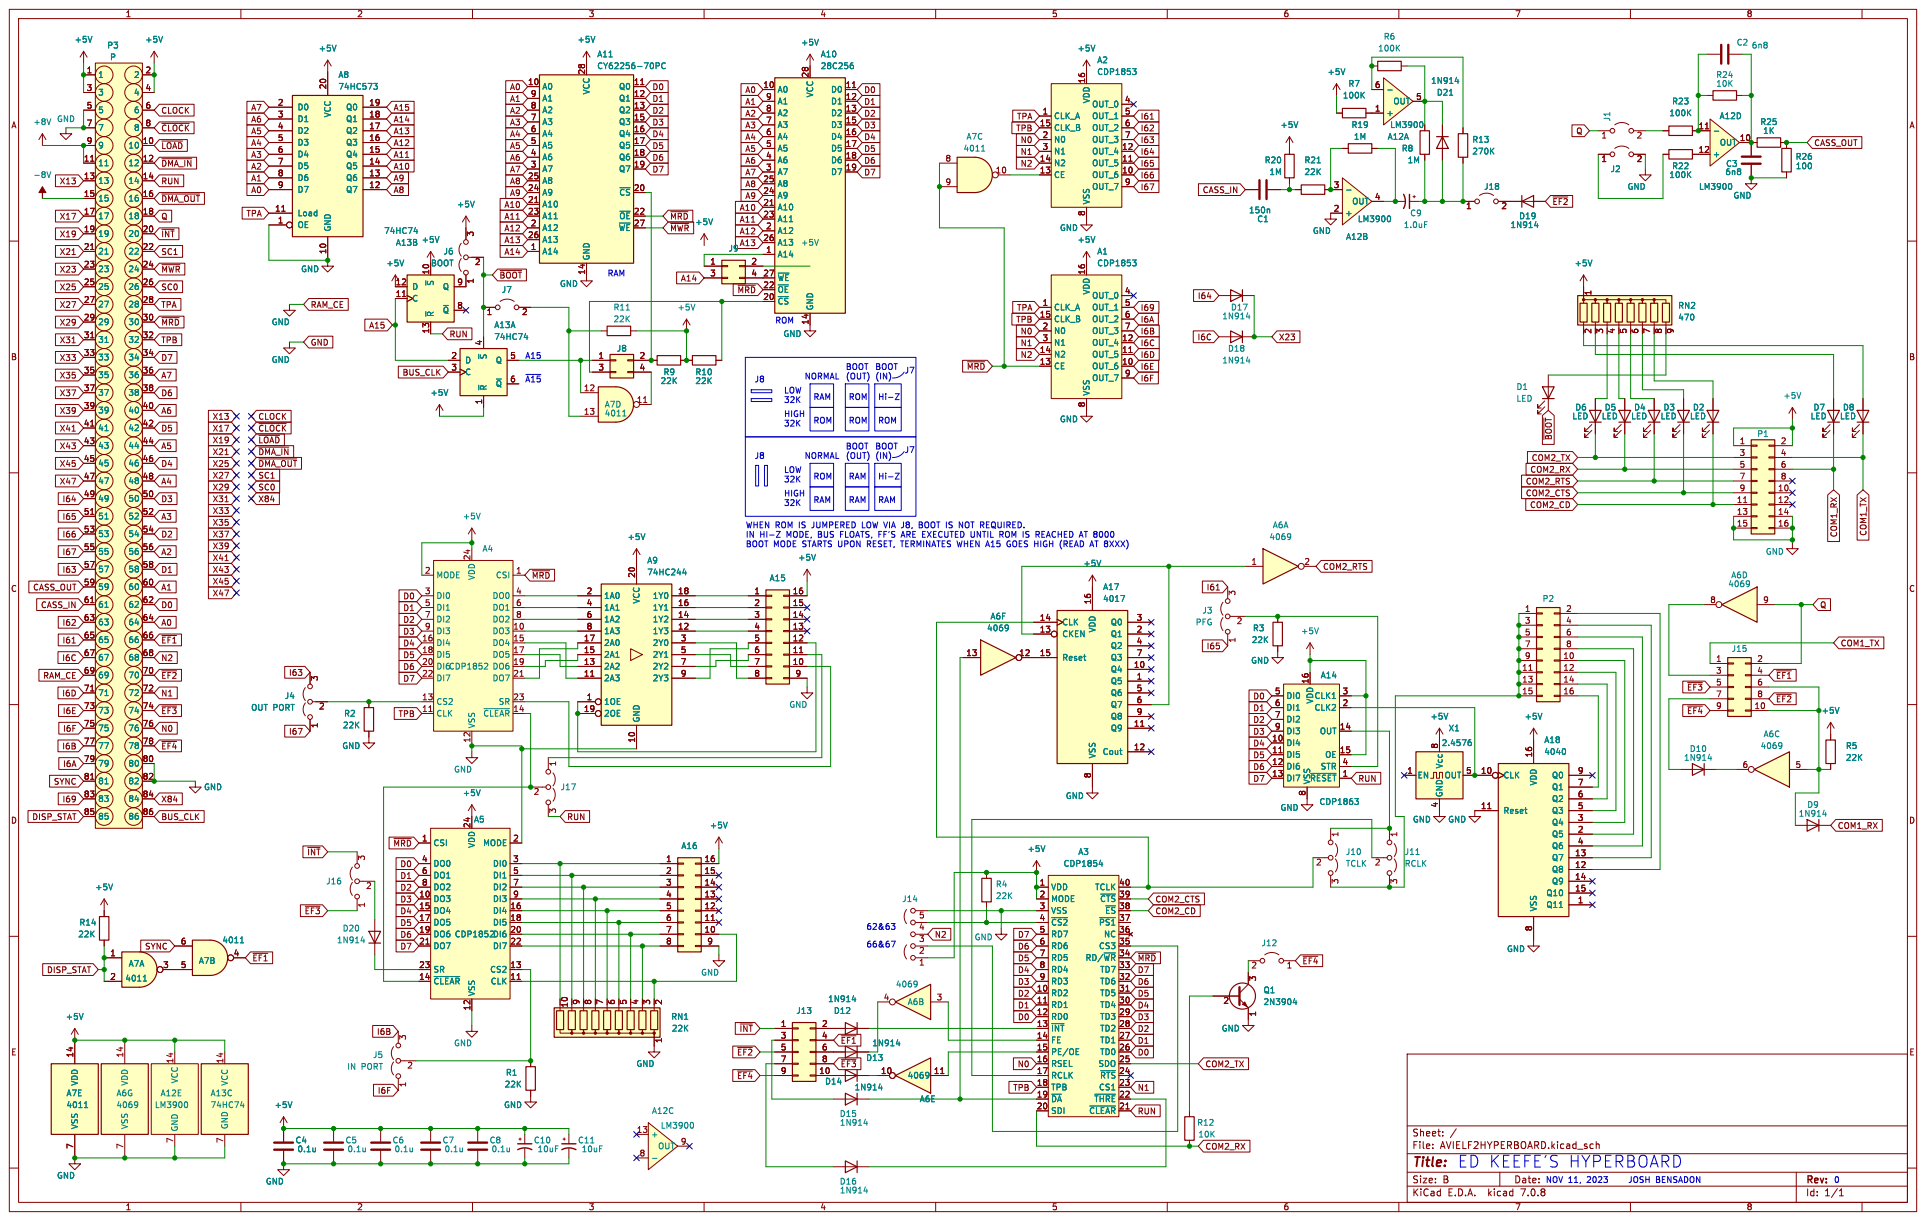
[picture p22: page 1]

J8 WHEN ROM IS JUMPERED LOW VIA J8, BOOT IS NOT REQUIRED.
IN HI-Z MODE, BUS FLOATS, FF'S ARE EXECUTED UNTIL ROM IS REACHED AT 8000 BOOT MODE STARTS UPON RESET, TERMINATES WHEN A15 GOES HIGH (READ AT 8XXX) LOW

4 OUT 5 Vcc 8 GND GND

Id: 1/1 Title: File: AVIELF2HYPERBOARD.kicad_sch Sheet: /

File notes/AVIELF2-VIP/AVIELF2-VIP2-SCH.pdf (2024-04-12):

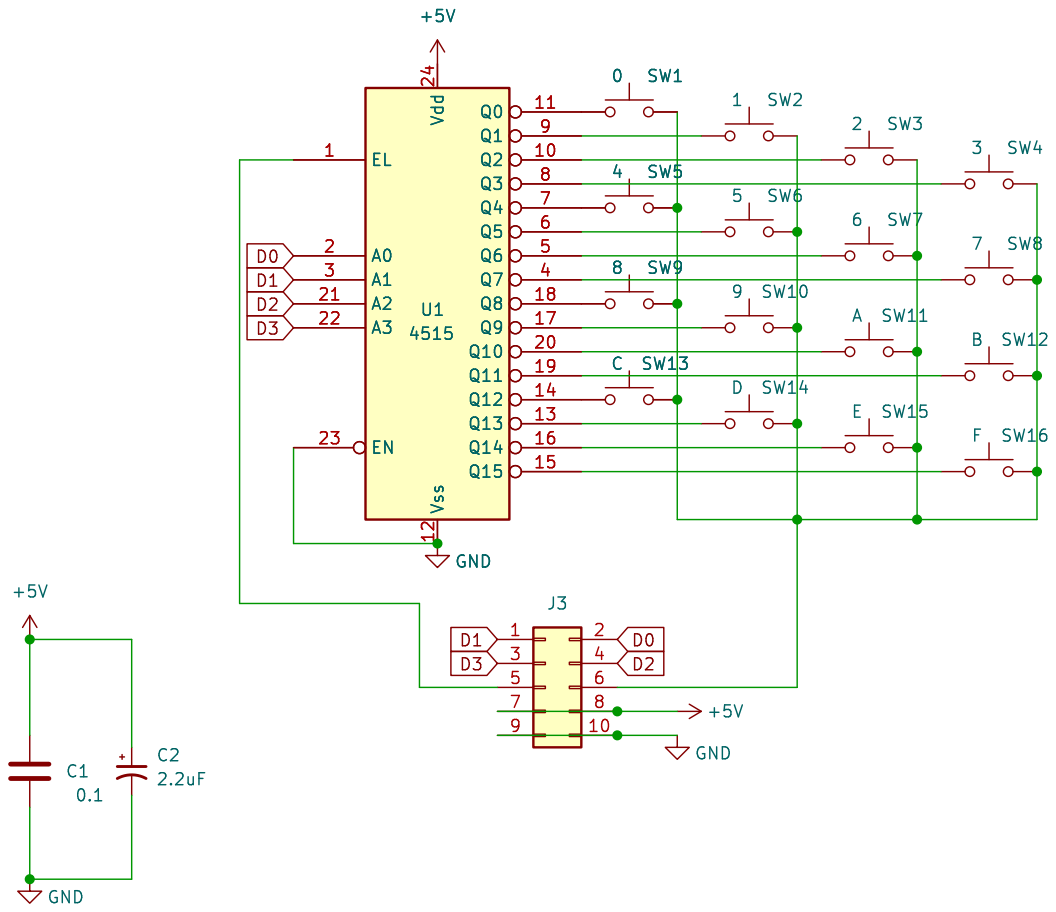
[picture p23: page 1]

10/23/2023 COSMAC 1802 BY JOSEPH WEISBECKER OCT 23, 2023 GND

Id: 1/1 Title: File: AVIELF2-VIP2.kicad_sch Sheet: / 1

DEDICATED TO THE MEMORY OF ED KEEFE
FOUNDER OF THE ELF II REPRODUCTION

PROJECT. DEVOTED RCA COSMAC DEVELOPER, ENGINEER, AND ALL ROUND GOOD GUY. JB, WM, AW

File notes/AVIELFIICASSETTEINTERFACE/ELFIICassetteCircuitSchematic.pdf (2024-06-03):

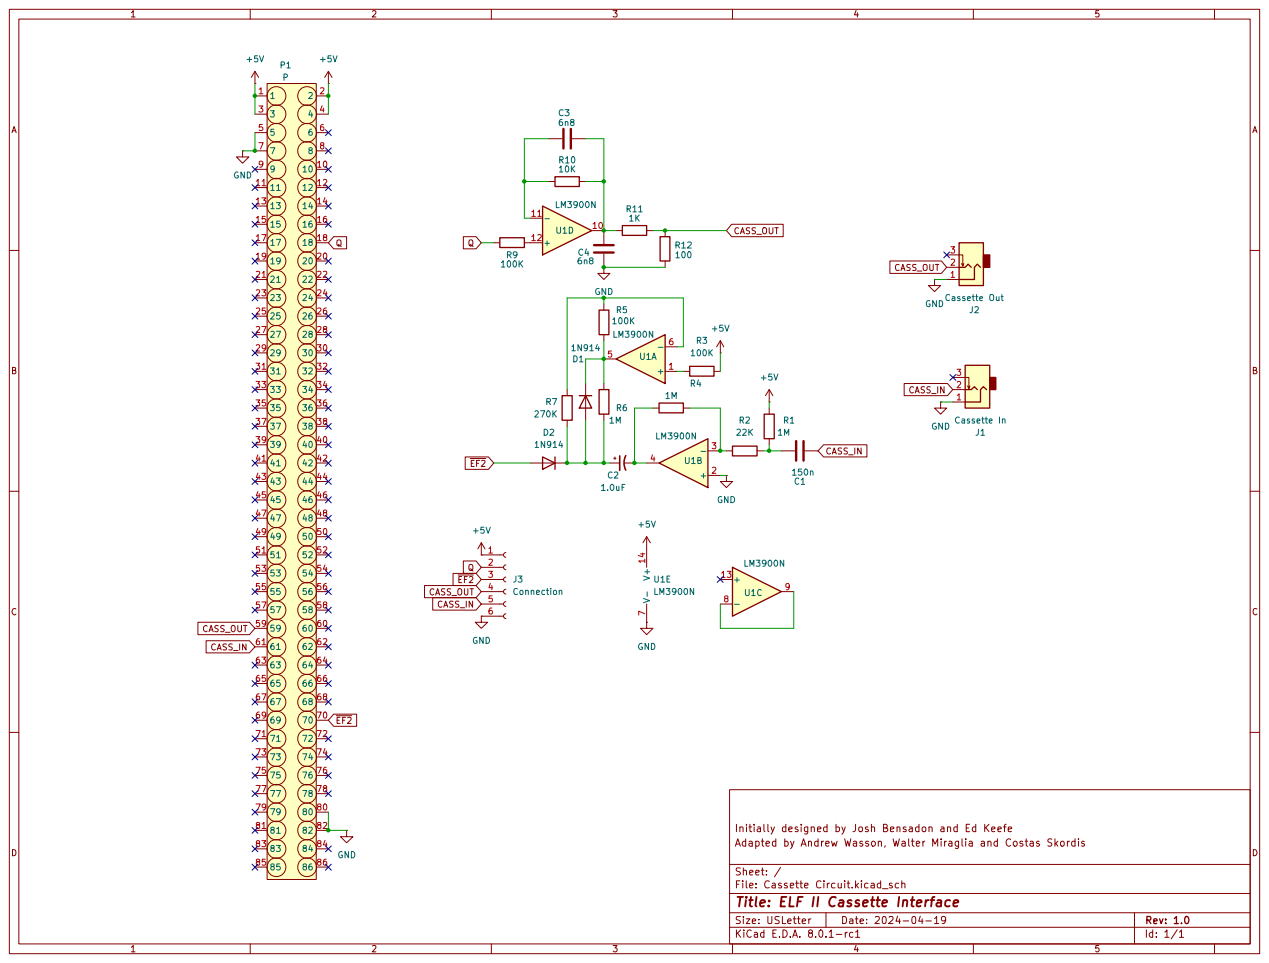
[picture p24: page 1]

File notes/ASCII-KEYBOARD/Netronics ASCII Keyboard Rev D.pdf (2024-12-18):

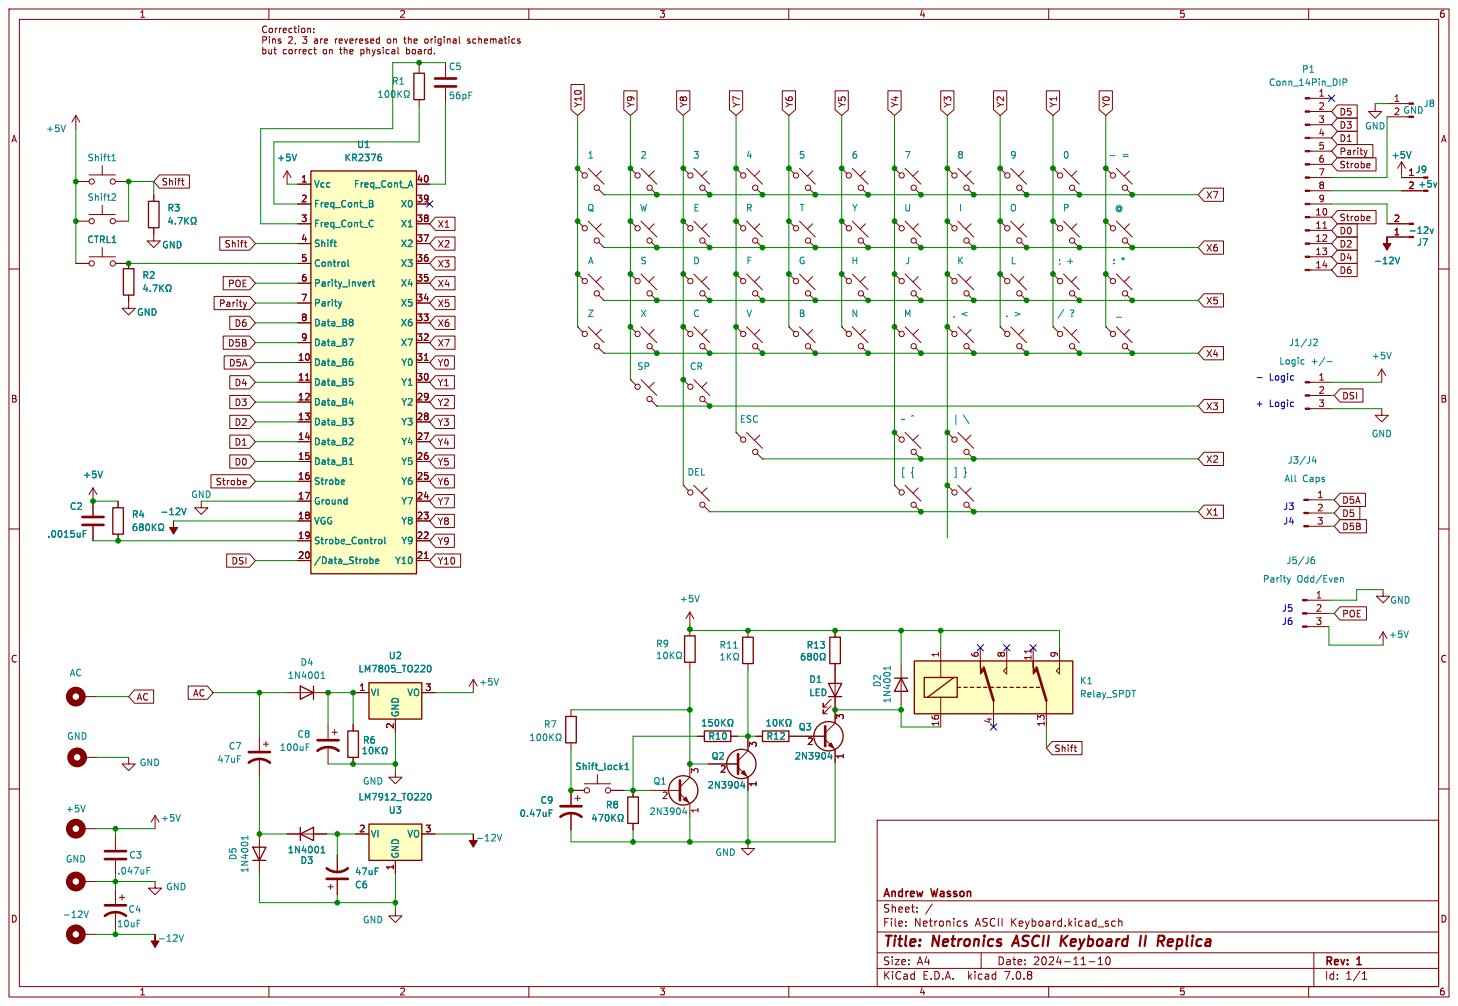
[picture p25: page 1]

Id: 1/1 Title: Netronics ASCII Keyboard II Replica

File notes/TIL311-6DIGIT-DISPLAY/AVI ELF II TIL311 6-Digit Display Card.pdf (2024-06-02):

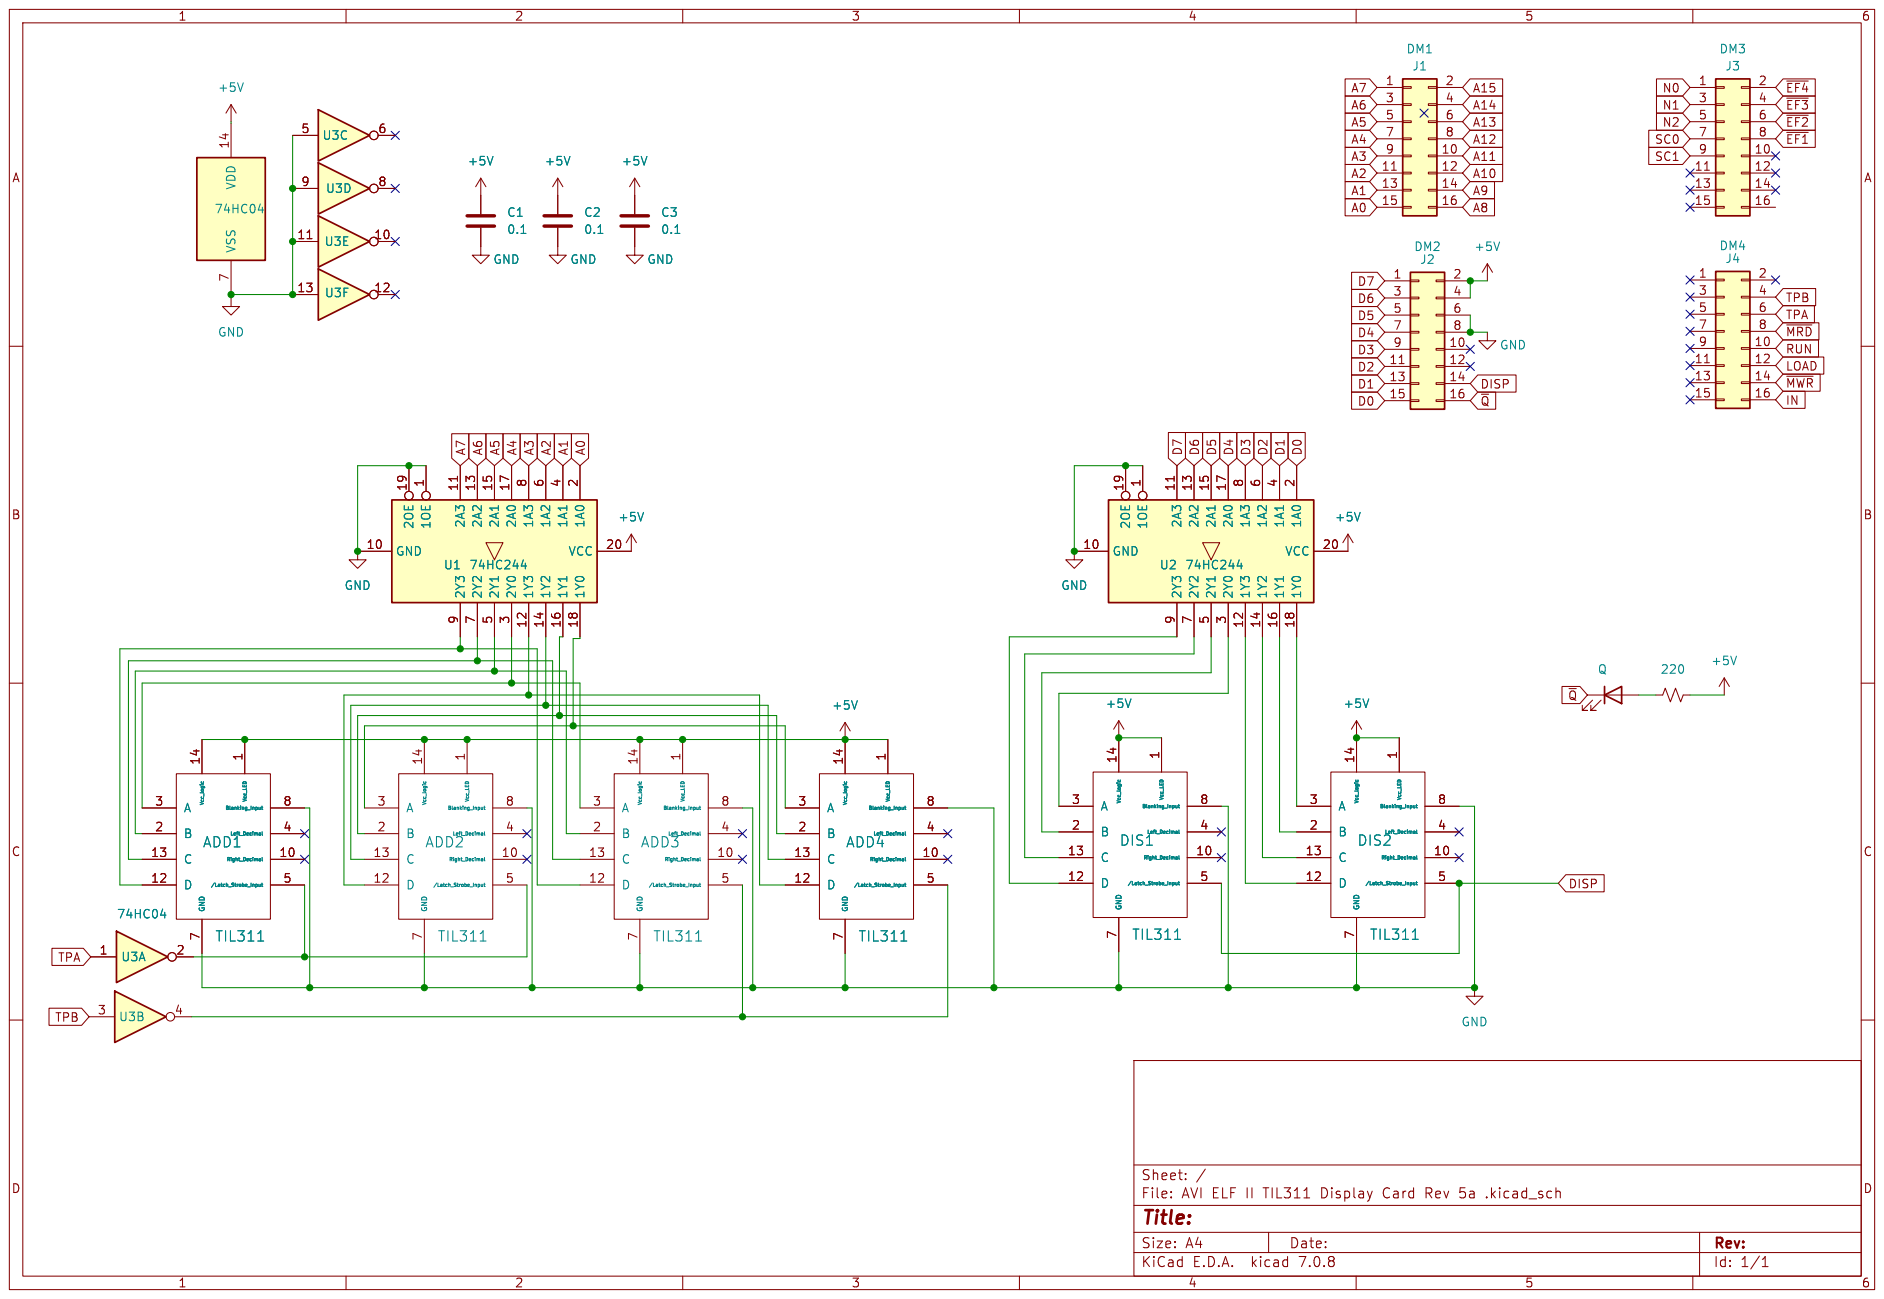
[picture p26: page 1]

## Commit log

2023-10-27 add photo and schematic
2023-10-28 update schematic
2023-11-01 update schematic and photo
2023-12-07 updates to BOM, images, gerbers, Kicad and schematic
    [AVI ELF II Final BOM.xlsx]
2023-12-07 Update README.md
    Update link to schematic
2023-12-14 update BOM
    [AVI ELF II Final BOM.xlsx]
2024-01-22 update Readme with new photo of prototype
2024-02-22 Update README.md
    Remove previous PCB image and update with current rev.
2024-02-22 Update README.md
    Update info on team and links to Assembly manual
2024-02-22 Update README.md
    Update PCB image
2024-02-22 Add subfolders for asset files for expansion cards
    [AVI ELF II Final BOM.xlsx]
2024-02-22 Update README.md
    Update readme for better flow
2024-02-25 Update BOM File
    [AVI ELF II Final BOM.xlsx]
2024-02-28 Update ELF II Gerbers
2024-02-28 Add Gerbers and Schematics for Expansion Boards
2024-02-29 Update README.md
    Update link to detailed assembly notes
2024-03-10 Add DigiKey BOM for Hyperboard
    [AVIELF2HYPERBOARD-BOM.xlsx]
2024-03-20 Update DigiKey BOM for Hyperboard
    [AVIELF2HYPERBOARD-BOM.xlsx]
2024-03-21 Update README.md
    Add LED Matrix Display Board to readme
2024-03-21 Update README.md
    Fix urls to collateral files for LED Matrix display card
2024-03-21 Update README.md
    Add link to LED Matrix Display assembly notes and fine tune description.
2024-03-21 Add prelim BOM's for VIP and SD Card
    [AVIELF2-VIP-BOM.xlsx, AVIELF2SD-BOM.xlsx]
2024-03-22 Add Hex File for Programming Pic chips for LED Matrix Display
2024-03-22 Update README.md
    Add link to HEX file for Programming the PIC 16F1826 Chips for the LED Matrix Board
2024-03-22 Update ELF II BOM regarding 74LS00 and 74HC74
    [AVI ELF II Final BOM.xlsx]
2024-04-04 Update VIP Card BOM
    [AVIELF2-VIP-BOM.xlsx]
2024-04-04 Sync Local VIP Card BOM
    [AVIELF2-VIP-BOM.xlsx]
2024-04-12 Update all schematics, images and gerbers
    [AVIELF2-VIP-BOM.xlsx]
2024-04-19 Update schematics
2024-04-24 Update SD Card BOM
    [AVIELF2SD-BOM.xlsx]
2024-04-29 Update VIP Card BOM & Add SD Firmware
    [AVIELF2DISPLAYMAX7219.csv, AVIELF2DISPLAYMAX7219.xlsx]
2024-04-30 Update VIP Card BOM Add Mouser
    [AVIELF2-VIP-BOM.xlsx]
2024-05-06 add triangle stl file
    [ELF_VIP_II_Triangle.stl]
2024-05-26 add preliminary BOM for STG card
    [AVIELFSTGDISK0-BOM.xlsx]
2024-05-30 updates to STG Card BOM
    [AVIELFSTGDISK0-BOM.xlsx]
2024-06-02 Add TIL311 6-Digit Board
2024-06-03 Add Cassette Board
2024-06-03 Update README.md
    note regarding current consumption when adding a 6-digit TIL311 board
2024-08-30 Add BOM for Cassette Board
2024-08-30 Remove BOM for Cassette Board
2024-08-30 fix ELF II BOM per Randy Eubanks notes
    [AVI ELF II Final BOM.xlsx]
2024-11-10 Add original schematic with notes to ASCII repo
2024-11-12 Add new schematic with highlighted keyboard matrix to ASCII repo
2024-12-07 updates to ASCII Keyboard schematic and notes
    [Netronics-ASCII-Keyboard-BOM.xlsx]
2024-12-08 updates to correct ASCII Keyboard schematic
2024-12-18 update ascii schematic and assets
2025-02-01 add Full Basic Math/Rom Board
    [Netronics-ASCII-Keyboard-BOM.xlsx]
2025-02-01 add schematic for Full Basic Math/Rom Board
2025-02-01 Update README.md
    Add Schematics for the Math/ROM card
2025-03-24 update ASCII Keyboard Gerbers, Schematic and Image
2025-03-24 Rename old Gerbers for ASCII Keyboard
2025-03-24 update ASCII Keyboard Gerbers
2025-08-26 Update README.md
    Update main page with info regarding the Math/BASIC/ROM board.
2025-11-24 add photos of netronics product board and programmer
2026-04-14 Update Repo with Rev 2.0 Hyperboard
    [AVIELF2HYPERBOARD-BOM.xlsx]
2026-04-17 Revise AVI Hyperboard details and update links
    Updated the AVI Hyperboard Expansion Card description to reflect the new version and added links to updated schematics and Gerber files.
2026-04-17 Update BOM for Hyperboard 2
    [AVIELF2HYPERBOARD-BOM.xlsx]
2026-05-26 Update Assembly Manual description in README
    Expanded the description of the Assembly Manual in the README to direct interested parties to the assembly manual (wiki).
2026-05-27 Update Gerbers and image of Hyperboard rev 2
2026-07-14 Add Josh Memory HYPERboard circuit
